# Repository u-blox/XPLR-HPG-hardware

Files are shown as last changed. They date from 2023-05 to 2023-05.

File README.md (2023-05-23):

# xplr-hpg-hw

This repository holds the design files for u-blox [XPLR-HPG-1](https://www.u-blox.com/en/product/xplr-hpg-1) and [XPLR-HPG-2](https://www.u-blox.com/en/product/xplr-hpg-2) hardware.

## [XPLR-HPG-1](https://www.u-blox.com/en/product/xplr-hpg-1)
XPLR-HPG-1 High Precision GNSS evaluation platform allows developers to evaluate the different u-blox solutions around high precision GNSS. The modular design of the base board (C213) offers users great flexibility in to explore high precision GNSS with different topologies and hardware. The design is based on the u-blox [NORA-W106](https://www.u-blox.com/en/product/nora-w10-series) that can act as a host and provides Wi-Fi and Bluetooth Low Energy v5.0 connectivity.
By using different u-blox module based MIKROE Click Boards, the user can evaluate different high precision GNSS topologies.

More info about the design can be found in the [XPLR-HPG-1 user guide](https://www.u-blox.com/en/product/xplr-hpg-1)

## [XPLR-HPG-2](https://www.u-blox.com/en/product/xplr-hpg-2)
XPLR-HPG-2 High Precision GNSS evaluation platform allows developers to evaluate the different u-blox solutions around high precision GNSS. In a simple form factor, XPLR-HPG-2 incorporates a high precision GNSS (u-blox [ZED-F9R](https://www.u-blox.com/en/product/zed-f9r-module)), an LTE Cat-1 cellular modem (u-blox [LARA-R6001D](https://www.u-blox.com/en/product/lara-r6-series)), a correction data L-BAND receiver (u-blox [NEO-D9S](https://www.u-blox.com/en/product/neo-d9s-series)) and a Wi-Fi capable host (u-blox [NINA-W106](https://www.u-blox.com/en/product/nina-w10-series-open-cpu)) to orchestrate the High precision GNSS functionality.

More info about the design can be found in the [XPLR-HPG-2 user guide](https://www.u-blox.com/en/product/xplr-hpg-2)

Software examples and libraries for both kits can be found in the [XPLR-HPG-Software](https://github.com/u-blox/XPLR-HPG-software) repo.

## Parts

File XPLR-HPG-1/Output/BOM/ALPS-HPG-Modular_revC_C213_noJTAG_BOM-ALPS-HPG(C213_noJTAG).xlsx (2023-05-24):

Line # | Designator | Quantity | Manufacturer 1 | Manufacturer Part Number 1 | Fitted | Supplier 1 | Supplier Part Number 1
 | BATT1 | 1 | Keystone Electronics | 1042 | Fitted | Mouser | 534-1042
 | BATT1_A, J3, J7 | 0 | Harwin | M20-9990246 | Not Fitted | Mouser | 855-M20-9990246
 | BATT1_B | 0 | JST | B2B-PH-SM4-TBT(LF)(SN) | Not Fitted | Future Electronics | 6881312
 | BTN1, BTN2 | 2 | TE Connectivity | FSMRA5JH | Fitted | Mouser | 506-1-1825027-4
 | BTN3 | 1 | ITT C&K | PTS526SK15SMTR2LFS | Fitted | Mouser | 611-PTS526SK15SMR2L
 | C1_1, C1_2, C1_3, C4, C6_1, C6_2, C22 | 7 | Yageo | CC0402KRX7R7BB104 | Fitted | Mouser | 603-CC402KRX7R7BB104
 | C2 | 1 | Murata | GRM155R61E105KA12D | Fitted | Mouser | 81-GRM155R61E105KA2D
 | C3, C9 | 2 | Murata | GRM21BR61E106KA73K | Fitted | Mouser | 81-GRM21BR61E106KA3K
 | C5 | 1 | Samsung | CL21A475KAQNNNG | Fitted | Mouser | 187-CL21A475KAQNNNG
 | C7, C8 | 0 | Murata | GCM1555C1H301FA16D | Not Fitted | Mouser | 81-GCM1555C1H301FA6D
 | C10, C25, C39_1, C39_2 | 4 | Yageo | CC0402KRX7R7BB104 | Fitted | Mouser | 603-CC402KRX7R7BB104
 | C11 | 1 | Yageo | CC0402KRX7R6BB683 | Fitted | Mouser | 603-CC402KRX7R6BB683
 | C12, C13 | 2 | KEMET | C1210C476M4PACTU | Fitted | Mouser | 80-C1210C476M4P
 | C14, C15 | 2 | Kyocera AVX | 08053C225KAT2A | Fitted | Mouser | 581-08053C225K
 | C16, C18 | 2 | TDK | C2012X7R1A475K125AC | Fitted | Mouser | 810-C2012X7R1A475K
 | C17, C19 | 2 | Yageo | CC0603KRX7R7BB104 | Fitted | Mouser | 603-CC603KRX7R7BB104
 | C20 | 1 | KEMET | C1210C476M4PACTU | Fitted | Mouser | 80-C1210C476M4P
 | C21, C29 | 2 | Yageo | CC0402KRX7R7BB104 | Fitted | Mouser | 603-CC402KRX7R7BB104
 | C23, C24 | 2 | Murata | GRM1885C1H102JA01D | Fitted | Mouser | 81-GRM39C102J50
 | C26 | 1 | Samsung | CL32A226KOJNNNE | Fitted | Mouser | 187-CL32A226KOJNNNE
 | C27, C28 | 0 | Murata | GRM155R71C223KA01D | Not Fitted | Mouser | 81-GRM155R71C223KA01
 | C30 | 1 | Yageo | CC0402KRX7R7BB104 | Fitted | Mouser | 603-CC402KRX7R7BB104
 | C31 | 1 | Yageo | CC0603KRX5R6BB475 | Fitted | Mouser | 603-CC603KRX5R6BB475
 | C32 | 1 | Yageo | CC0402KRX5R6BB224 | Fitted | Mouser | 603-CC402KRX5R6BB224
 | C33 | 1 | Yageo | CC0603KRX7R7BB104 | Fitted | Mouser | 603-CC603KRX7R7BB104
 | C34_1, C34_2, C34_3 | 0 | KEMET | C1210C476M4PACTU | Not Fitted | Mouser | 80-C1210C476M4P
 | C35 | 1 | Murata | GRM21BR60J226ME39L | Fitted | Mouser | 81-GRM21R60J226ME39L
 | C36, C37 | 2 | Murata | GRM21BR61E226ME44L | Fitted | Mouser | 81-GRM21BR61E226ME4L
 | C38 | 1 | Murata | GCM188R72A103KA37D | Fitted | Mouser | 81-GCM188R72A103KA7D
 | C40 | 1 | Murata | GRM155R61E105KA12D | Fitted | Mouser | 81-GRM155R61E105KA2D
 | D1_1, D1_2 | 2 | Wurth Electronics | 824011 | Fitted | Mouser | 710-824011
 | D2, D10, D11 | 3 | Wurth Electronics | 150060VS75000 | Fitted | Mouser | 710-150060VS75000
 | D3 | 1 | Wurth Electronics | 150060YS75000 | Fitted | Mouser | 710-150060YS75000
 | D4, D5 | 2 | Wurth Electronics | 150060RS75000 | Fitted | Mouser | 710-150060RS75000
 | D6, D7 | 2 | ON Semiconductor | BZX84C6V2LT1G | Fitted | Mouser | 863-BZX84C6V2LT1G
 | D8, D9 | 0 | Wurth Electronics | 150060VS75000 | Not Fitted | Mouser | 710-150060VS75000
 | D12 | 1 | Nexperia | PRTR5V0U2X,215 | Fitted | Mouser | 771-PRTR5V0U2X-T/R
 | D13 | 1 | Diodes | DT1042-04SO-7 | Fitted | Mouser | 621-DT1042-04SO-7
 | F1_1, F1_2 | 2 | Murata | BLM18EG221TN1D | Fitted | Mouser | 81-BLM18EG221TN1D
 | J1 | 1 | Global Connector Technology | MEM2080-00-128-00-A | Fitted | Mouser | 640-MEM2080-0012800A
 | J2 | 1 | JST | SM03B-SRSS-TB(LF)(SN) | Fitted | Farnell | 1679118
 | J4 | 0 | Samtec | FTSH-105-01-F-DV-K | Not Fitted | Mouser | 200-FTSH10501FDVK
 | J5 | 1 | Wurth Electronics | 61300311121 | Fitted | Mouser | 710-61300311121
 | J6_1, J6_2 | 2 | JAE Electronics | DX07S024JJ3R1300 | Fitted | Mouser | 656-DX07S024JJ3R1300
 | J18 | 0 | Molex | 51281-0594 | Not Fitted | Digi-Key | WM12846DKR-ND
 | J22 | 1 | SparkFun | PRT-14417 | Fitted | Mouser | 474-PRT-14417
 | L3 | 1 | Coilcraft | XFL4020-102MEC | Fitted | Mouser | 994-XFL4020-102MEC
 | MB_1, MB_2, MB_3 | 3 |  |  | Fitted
 | NT1 | 1 | Vishay Dale | NTHS0603N02N1002JR | Fitted | Mouser | 71-NTHS0603N02N1002J
 | PCB | 1 |  | UBXH60-0001010 | Fitted
 | Q1, Q3 | 2 | Toshiba | SSM6N56FE,LM | Fitted | Mouser | 757-SSM6N56FELM
 | Q2A | 1 | ON Semiconductor | EFC6611R-TF | Fitted | Mouser | 863-EFC6611R-TF
 | Q2B | 0 | ON Semiconductor | ECH8693R-TL-W | Not Fitted | Mouser | 863-ECH8693R-TL-W
 | Q4 | 1 | ON Semiconductor | SMBT3904DW1T1G | Fitted | Mouser | 863-SMBT3904DW1T1G
 | R1, R7, R9 | 3 | Yageo | RC0402FR-07100KL | Fitted | Mouser | 603-RC0402FR-07100KL
 | R2, R86 | 0 | Yageo | RC0402JR-074K7L | Not Fitted | Mouser | 603-RC0402JR-074K7L
 | R3, R57, R59, R89 | 4 | Yageo | RC0402JR-0710KL | Fitted | Mouser | 603-RC0402JR-0710KL
 | R4 | 1 | Yageo | RC0402FR-071K5L | Fitted | Mouser | 603-RC0402FR-071K5L
 | R5_1, R5_2, R6_1, R6_2 | 4 | Panasonic | ERJ-2RKF27R0X | Fitted | Mouser | 667-ERJ-2RKF27R0X
 | R8 | 1 | Yageo | RC0402FR-07499RL | Fitted | Mouser | 603-RC0402FR-07499RL
 | R10, R11 | 2 | Panasonic | ERJ-2GEJ221X | Fitted | Mouser | 667-ERJ-2GEJ221X
 | R12, R13, R16, R18 | 0 | Yageo | RC0402FR-07100KL | Not Fitted | Mouser | 603-RC0402FR-07100KL
 | R14 | 1 | Yageo | RC0402FR-072K2L | Fitted | Mouser | 603-RC0402FR-072K2L
 | R15, R20, R35, R36, R38, R41, R53, R55, R70, R71, R78, R80, R82, R84, R85, R91 | 0 | Bourns | CR0402-J/-000GLF | Not Fitted | Mouser | 652-CR0402-J/-000GLF
 | R17, R19, R21, R34, R37, R69, R77, R79, R81, R83, R90 | 11 | Bourns | CR0402-J/-000GLF | Fitted | Mouser | 652-CR0402-J/-000GLF
 | R22, R23 | 2 | Yageo | RC0603FR-072K2L | Fitted | Mouser | 603-RC0603FR-072K2L
 | R24, R26, R28, R30, R32, R33 | 6 | Yageo | RC0402JR-071ML | Fitted | Mouser | 603-RC0402JR-071ML
 | R25, R27, R29, R31, R60, R61, R87, R88 | 8 | Yageo | RC0402JR-074K7L | Fitted | Mouser | 603-RC0402JR-074K7L
 | R39 | 0 | Yageo | RC0402JR-0710KL | Not Fitted | Mouser | 603-RC0402JR-0710KL
 | R40, R62 | 2 | Yageo | RC0805JR-070RL | Fitted | Mouser | 603-RC0805JR-070RL
 | R42, R51 | 2 | Yageo | RC0603JR-073K3L | Fitted | Mouser | 603-RC0603JR-073K3L
 | R43 | 1 | Yageo | RC0402FR-0722KL | Fitted | Mouser | 603-RC0402FR-0722KL
 | R44 | 1 | Yageo | RC0402FR-0747KL | Fitted | Mouser | 603-RC0402FR-0747KL
 | R45 | 0 | Yageo | RC0603JR-070RL | Not Fitted | Mouser | 603-RC0603JR-070RL
 | R46, R56, R58 | 3 | Yageo | RC0603JR-070RL | Fitted | Mouser | 603-RC0603JR-070RL
 | R47, R73 | 2 | Yageo | RC0402FR-071KL | Fitted | Mouser | 603-RC0402FR-071KL
 | R48, R52 | 2 | Yageo | RC0603FR-07470RL | Fitted | Mouser | 603-RC0603FR-07470RL
 | R49, R50 | 2 | Panasonic | ERJ-3EKF9100V | Fitted | Mouser | 667-ERJ-3EKF9100V
 | R54_1, R54_2, R67_1, R67_2 | 4 | Panasonic | ERJ-2GEJ512X | Fitted | Mouser | 667-ERJ-2GEJ512X
 | R63 | 1 | Yageo | RC0402FR-0716KL | Fitted | Mouser | 603-RC0402FR-0716KL
 | R64 | 1 | Panasonic | ERJ-2RKF3003X | Fitted | Mouser | 667-ERJ-2RKF3003X
 | R65 | 1 | Yageo | RC0402FR-07100KL | Fitted | Mouser | 603-RC0402FR-07100KL
 | R66 | 1 | Panasonic | ERJ-2RKF1003X | Fitted | Mouser | 667-ERJ-2RKF1003X
 | R68_1, R68_2 | 2 | Yageo | RC0402JR-0710KL | Fitted | Mouser | 603-RC0402JR-0710KL
 | R72 | 1 | Yageo | RC0402FR-071KL | Fitted | Mouser | 603-RC0402FR-071KL
 | R74 | 1 | Panasonic | ERJ-2RKF4700X | Fitted | Mouser | 667-ERJ-2RKF4700X
 | R75 | 0 | KOA Speer | RK73Z2BTTD | Not Fitted | Mouser | 660-RK73Z2BTTD
 | R76 | 0 | Yageo | RC0805JR-070RL | Not Fitted | Mouser | 603-RC0805JR-070RL
 | R92 | 1 | Yageo | RC0402FR-0747KL | Fitted | Mouser | 603-RC0402FR-0747KL
 | RGB | 1 | Vishay Lite-On | LTST-C19HE1WT | Fitted | Mouser | 859-LTST-C19HE1WT
 | SW1 | 1 | ITT C&K | OS102011MA1QN1 | Fitted | Mouser | 611-OS102011MA1QN1
 | U1 | 1 | u-blox | NORA-W106-00B | Fitted | Mouser | 377-NORA-W106-00B
 | U2 | 0 | Macronix | MX25R6435FZNIL0 | Not Fitted | Future Electronics | 5069038
 | U3A | 1 | Silicon Labs | CP2102N-A02-GQFN24 | Fitted | Mouser | 634-CP2102NA02GQFN24
 | U4 | 1 | ABLIC | S-82N1AAA-I6T1U7 | Fitted | Mouser | 628-S-82N1AAA-I6T1U7
 | U5 | 1 | Broadcom Avago | HCPL-073L-000E | Fitted | Mouser | 630-HCPL-073L-000E
 | U6 | 1 | Texas Instruments | SN74LVC2G07DBVR | Fitted | Mouser | 595-SN74LVC2G07DBVR
 | U7 | 1 | Texas Instruments | TPS61230ARNSR | Fitted | Mouser | 595-TPS61230ARNSR
 | U8 | 1 | ON Semiconductor | NCP690MN33T2G | Fitted | Mouser | 863-NCP690MN33T2G
 | U9B | 1 | Texas Instruments | SN74LVC1G06DBVR | Fitted | Mouser | 595-SN74LVC1G06DBVR
 | U10 | 1 | Maxim | MAX8934DETI+ | Fitted | Mouser | 700-MAX8934DETI+

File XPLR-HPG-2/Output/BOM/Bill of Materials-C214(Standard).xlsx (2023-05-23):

Designator | Quantity | Manufacturer 1 | Manufacturer Part Number 1 | Fitted | Supplier 1 | Supplier Part Number 1
BT1 | 1 | Seiko | ML414H-IV01E | Fitted | Mouser | 628-ML414H-IV01E
C1, C3, C5, C7, C12, C13, C35, C49 | 8 | KEMET | C0603C105M4RACTU | Fitted | Mouser | 80-C0603C105M4R
C2, C4, C6, C9, C11, C17, C19, C25, C26, C31, C32, C36 | 12 | KEMET | C0603C104J3RACTU | Fitted | Mouser | 80-C0603C104J3R
C8 | 1 | KEMET | C0603C102K5RACTU | Fitted | Mouser | 80-C0603C102K5R
C10, C27, C28 | 3 | Murata | GRM188R6YA475KE15D | Fitted | Mouser | 81-GRM188R6YA475KE5D
C14, C15, C37, C38, C39, C40 | 6 | KEMET | C0603C470J5GACTU | Fitted | Mouser | 80-C0603C470J5G
C16 | 1 | KEMET | T520D337M006ATE045 | Fitted | Mouser | 80-T520D337M006
C18 | 1 | Murata | GRM188R60J106ME47D | Fitted | Mouser | 81-GRM188R60J106ME47
C20 | 1 | KEMET | C0603C680J5GACTU | Fitted | Mouser | 80-C0603C680J5G
C21 | 1 | Kyocera AVX | TAJA106K016RNJ | Fitted | Mouser | 581-TAJA106K016R
C22 | 1 | Kyocera AVX | 06035A150JAT2A | Fitted | Mouser | 581-06035A150J
C23, C29, C30 | 3 | Murata | GCM188R71E224KA55D | Fitted | Mouser | 81-GCM188R71E224K55D
C24 | 1 | KEMET | C0603C829K5GACTU | Fitted | Mouser | 80-C0603C829K5G
C33, C34 | 2 | Murata | GRM1555C1H330JA01D | Fitted | Arrow Electronics | GRM1555C1H330JA01D
C41 | 0 | KEMET | C0603C105M4RACTU | Not Fitted | Mouser | 80-C0603C105M4R
C42 | 1 | KEMET | C0603C104J3RACTU | Fitted | Mouser | 80-C0603C104J3R
C43 | 1 | Taiyo Yuden | TMK316BJ106MLHT | Fitted | Mouser | 963-TMK316BJ106MLHT
C44, C46 | 2 | KEMET | C0603C105M4RACTU | Fitted | Mouser | 80-C0603C105M4R
C45, C48 | 2 | Taiyo Yuden | LMK316AB7226KL-TR | Fitted | Mouser | 963-LMK316AB7226KLTR
C47 | 1 | KEMET | C0603C104J3RACTU | Fitted | Mouser | 80-C0603C104J3R
C50 | 0 | Murata | GRM32EE70J107ME15L | Not Fitted | Mouser | 81-GRM32EE70J107ME5L
C51, C52 | 0 |  |  | Not Fitted
D1, D4, D7, D19 | 4 | Osram Opto | LB Q39G-L2OO-35-1 | Fitted | Mouser | 720-LBQ39GL2N2351
D2 | 1 | Vishay Lite-On | LTST-C190YKT | Fitted | Mouser | 859-LTST-C190YKT
D3, D9, D17, D20 | 4 | Vishay Lite-On | LTST-C190EKT | Fitted | Mouser | 859-LTST-C190EKT
D5, D12, D13 | 3 | Littelfuse | PESD0402-140 | Fitted | Mouser | 650-PESD0402-140
D6 | 1 | Nexperia | PMEG4005EJ,115 | Fitted | Arrow Electronics | PMEG4005EJ,115
D8, D18 | 2 | Vishay Lite-On | LTST-C190KGKT | Fitted | Mouser | 859-LTST-C190KGKT
D10 | 1 | Wurth Electronics | 824011 | Fitted | Mouser | 710-824011
D11, D16 | 2 | Diodes | DT1042-04SO-7 | Fitted | Mouser | 621-DT1042-04SO-7
D14 | 1 | Nexperia | PRTR5V0U2X,215 | Fitted | Mouser | 771-PRTR5V0U2X-T/R
E1, E2, E3 | 3 | Amphenol Connex | 132322 | Fitted | Mouser | 523-132322
F1 | 1 | Littelfuse | 1210L200SLYR | Fitted | Mouser | 576-1210L200SLYR
F2, F3 | 2 | Murata | BLM18EG221TN1D | Fitted | Mouser | 81-BLM18EG221TN1D
F4 | 1 | Littelfuse | 1206L110THYR | Fitted | Mouser | 576-1206L110THYR
J1 | 1 | Global Connector Technology | USB4105-GF-A | Fitted | Mouser | 640-USB4105-GF-A
J2, J5 | 0 | Amphenol ICC / FCI | 77311-418-12LF | Not Fitted | Mouser | 649-77311-418-12LF
J3 | 1 | Global Connector Technology | MEM2075-00-140-01-A | Fitted | Mouser | 640-MEM20750014001A
J4 | 0 | Global Connector Technology | BG301-03-A-0540-L-B | Not Fitted | Future Electronics | 7018791
J6 | 1 | SparkFun | PRT-14417 | Fitted | Mouser | 474-PRT-14417
J7 | 1 | Adafruit Industries | 1769 | Fitted | Mouser | 485-1769
J8 | 0 | Harwin | M20-9990246 | Not Fitted | Mouser | 855-M20-9990246
J9 | 1 | Hirose | KP13B-SF-PEJ(800) | Fitted | Mouser | 798-KP13B-SF-PEJ800
J10 | 0 | Amphenol ICC / FCI | 68422-410HLF | Not Fitted | Mouser | 649-68422-410HLF
J11 | 0 | Samtec | FTSH-105-01-F-DV-K | Not Fitted | Mouser | 200-FTSH10501FDVK
L1, L2 | 0 |  |  | Not Fitted
L3 | 1 | Murata | DFE322520FD-1R5M=P2 | Fitted | Mouser | 81-DFE322520FD1R5MP2
L4 | 1 | Murata | LQG15HN47NJ02D | Fitted | Mouser | 81-LQG15HN47NJ02D
L5, L6 | 2 | Murata | LQG15HN12NG02D | Fitted | Mouser | 81-LQG15HN12NG02D
PCB | 1 |  | UBXH60-0000969 | Fitted
Q1 | 1 | ON Semiconductor | MBT3904DW1T1G | Fitted | Mouser | 863-MBT3904DW1T1G
Q2, Q3, Q5, Q6 | 4 | ON Semiconductor / Fairchild | 2N7002KW | Fitted | Mouser | 512-2N7002KW
R1, R9, R11, R14, R32, R34, R38, R42, R43, R46, R49 | 11 | Yageo | RC0603FR-07100KL | Fitted | Mouser | 603-RC0603FR-07100KL
R2, R6, R10, R39, R40, R44, R47, R48, R50 | 9 | Yageo | RC0603FR-071KL | Fitted | Mouser | 603-RC0603FR-071KL
R3 | 1 | Yageo | RC0603FR-072K7L | Fitted | Mouser | 603-RC0603FR-072K7L
R4 | 1 | Yageo | RC0603FR-0747KL | Fitted | Mouser | 603-RC0603FR-0747KL
R5, R7 | 2 | Yageo | RC0603FR-075K1L | Fitted | Mouser | 603-RC0603FR-075K1L
R8 | 1 | Yageo | RC0603FR-074K7L | Fitted | Mouser | 603-RC0603FR-074K7L
R12, R30 | 2 | Yageo | RC0603FR-0722KL | Fitted | Mouser | 603-RC0603FR-0722KL
R13 | 1 | Panasonic | ERJ-3EKF4752V | Fitted | Mouser | 667-ERJ-3EKF4752V
R15, R18, R19 | 3 | Yageo | RC0603FR-072K2L | Fitted | Mouser | 603-RC0603FR-072K2L
R16, R17 | 2 | Yageo | RC0603FR-0710KL | Fitted | Mouser | 603-RC0603FR-0710KL
R20, R21, R22, R23 | 4 | Panasonic | ERJ-3EKF27R0V | Fitted | Mouser | 667-ERJ-3EKF27R0V
R24 | 1 | Yageo | RC0603FR-0720KL | Fitted | Mouser | 603-RC0603FR-0720KL
R25, R45 | 2 | Yageo | RC0603FR-07100RL | Fitted | Mouser | 603-RC0603FR-07100RL
R26, R27, R28, R56, R58 | 5 | Yageo | RC0603FR-072KL | Fitted | Mouser | 603-RC0603FR-072KL
R29 | 1 | Yageo | RC0603FR-071KL | Fitted | Mouser | 603-RC0603FR-071KL
R31 | 1 | Yageo | RC0603FR-0733KL | Fitted | Mouser | 603-RC0603FR-0733KL
R33, R51, R64, R67 | 0 | Yageo | RC0603FR-100RL | Not Fitted | Mouser | 603-RC0603FR-100RL
R35, R59, R60, R61 | 4 | Yageo | RC0603FR-0710KL | Fitted | Mouser | 603-RC0603FR-0710KL
R36 | 1 | Yageo | RC0603FR-07200KL | Fitted | Mouser | 603-RC0603FR-07200KL
R37 | 1 | Panasonic | ERJ-P06D16R9V | Fitted | Mouser | 667-ERJ-P06D16R9V
R41 | 1 | Yageo | RC0603FR-07220RL | Fitted | Mouser | 603-RC0603FR-07220RL
R53, R55 | 0 | Yageo | RC0603FR-100RL | Not Fitted | Mouser | 603-RC0603FR-100RL
R54 | 1 | Yageo | RC0603FR-100RL | Fitted | Mouser | 603-RC0603FR-100RL
R57 | 1 | Yageo | RC0603FR-0721KL | Fitted | Mouser | 603-RC0603FR-0721KL
R62 | 1 | Yageo | RC0603FR-0757K6L | Fitted | Mouser | 603-RC0603FR-0757K6L
R63 | 1 | Yageo | RC0603FR-074K7L | Fitted | Mouser | 603-RC0603FR-074K7L
R65 | 1 | Yageo | RC0603FR-0710KL | Fitted | Mouser | 603-RC0603FR-0710KL
R66 | 1 | Yageo | RC0603FR-100RL | Fitted | Mouser | 603-RC0603FR-100RL
R68 | 0 | Yageo | RC0603FR-0710KL | Not Fitted | Mouser | 603-RC0603FR-0710KL
S1, S2, S3 | 3 | ITT C&K | PTS526SK15SMTR2LFS | Fitted | Mouser | 611-PTS526SK15SMR2L
U1 | 1 | u-blox | NINA-W106-10B | Fitted | Mouser | 377-NINA-W106-10B
U2 | 1 | Silicon Labs | CP2102N-A02-GQFN24 | Fitted | Mouser | 634-CP2102NA02GQFN24
U3 | 1 | u-blox | NEO-D9S-00B | Fitted | Mouser | 377-NEO-D9S-00B
U4 | 1 | u-blox | ZED-F9R-02B | Fitted | Digi-Key | 672-ZED-F9R-02BCT-ND
U5 | 1 | Anaren | PD0922J5050S2HF | Fitted | Mouser | 620-PD0922J5050S2HF
U6 | 1 | u-blox | LARA-R6001D-00B | Fitted | Mouser | 377-LARA-R6001D-00B
U7 | 1 | ON Semiconductor | NCP690MNADJT2G | Fitted | Mouser | 863-NCP690MNADJT2G
U8 | 1 | ON Semiconductor | NCP690MN33T2G | Fitted | Mouser | 863-NCP690MN33T2G
U9 | 1 | Texas Instruments | PCA9306DCUR | Fitted | Mouser | 595-PCA9306DCUR
U10, U13 | 2 | Nexperia | 74AVC4T774PWJ | Fitted | Mouser | 771-74AVC4T774PWJ
U11 | 1 | Texas Instruments | SN74LVC1G04DCKR | Fitted | Mouser | 595-SN74LVC1G04DCKR
U12 | 1 | Monolithic Power Systems | MP2617HGL-Z | Fitted | Mouser | 946-MP2617HGL-Z
U14 | 1 | Terminus Tech | FE1.1S-BSOP28BCN | Fitted | LCSC ELECTRONICS | C9359
Y1 | 1 | Wurth Electronics | 830036401 | Fitted | Mouser | 710-830036401

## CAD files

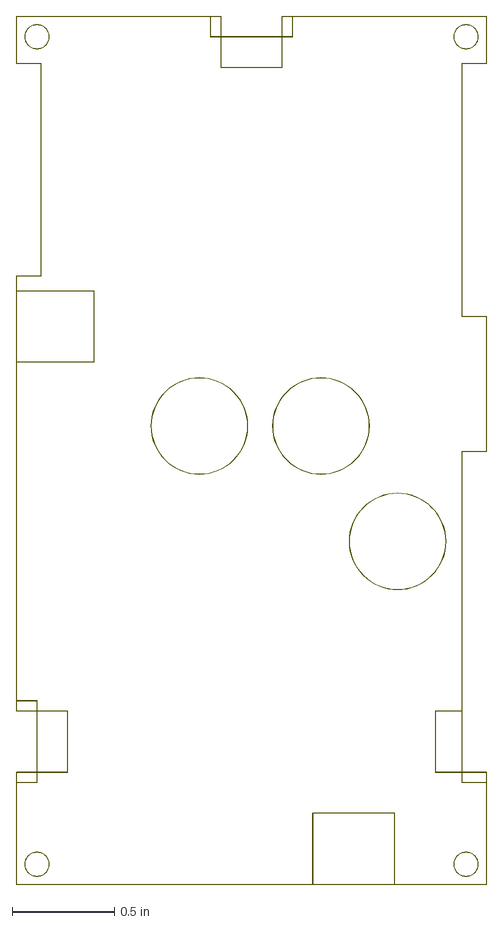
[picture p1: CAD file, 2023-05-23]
XPLR-HPG-2/Output/Plexiglass/Plexiglass_Top_Bottom.DXF
2.30 x 4.25 in

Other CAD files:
XPLR-HPG-1/Plexi Design/C213,C215_revC_Plexiglass_wLetters.dxf

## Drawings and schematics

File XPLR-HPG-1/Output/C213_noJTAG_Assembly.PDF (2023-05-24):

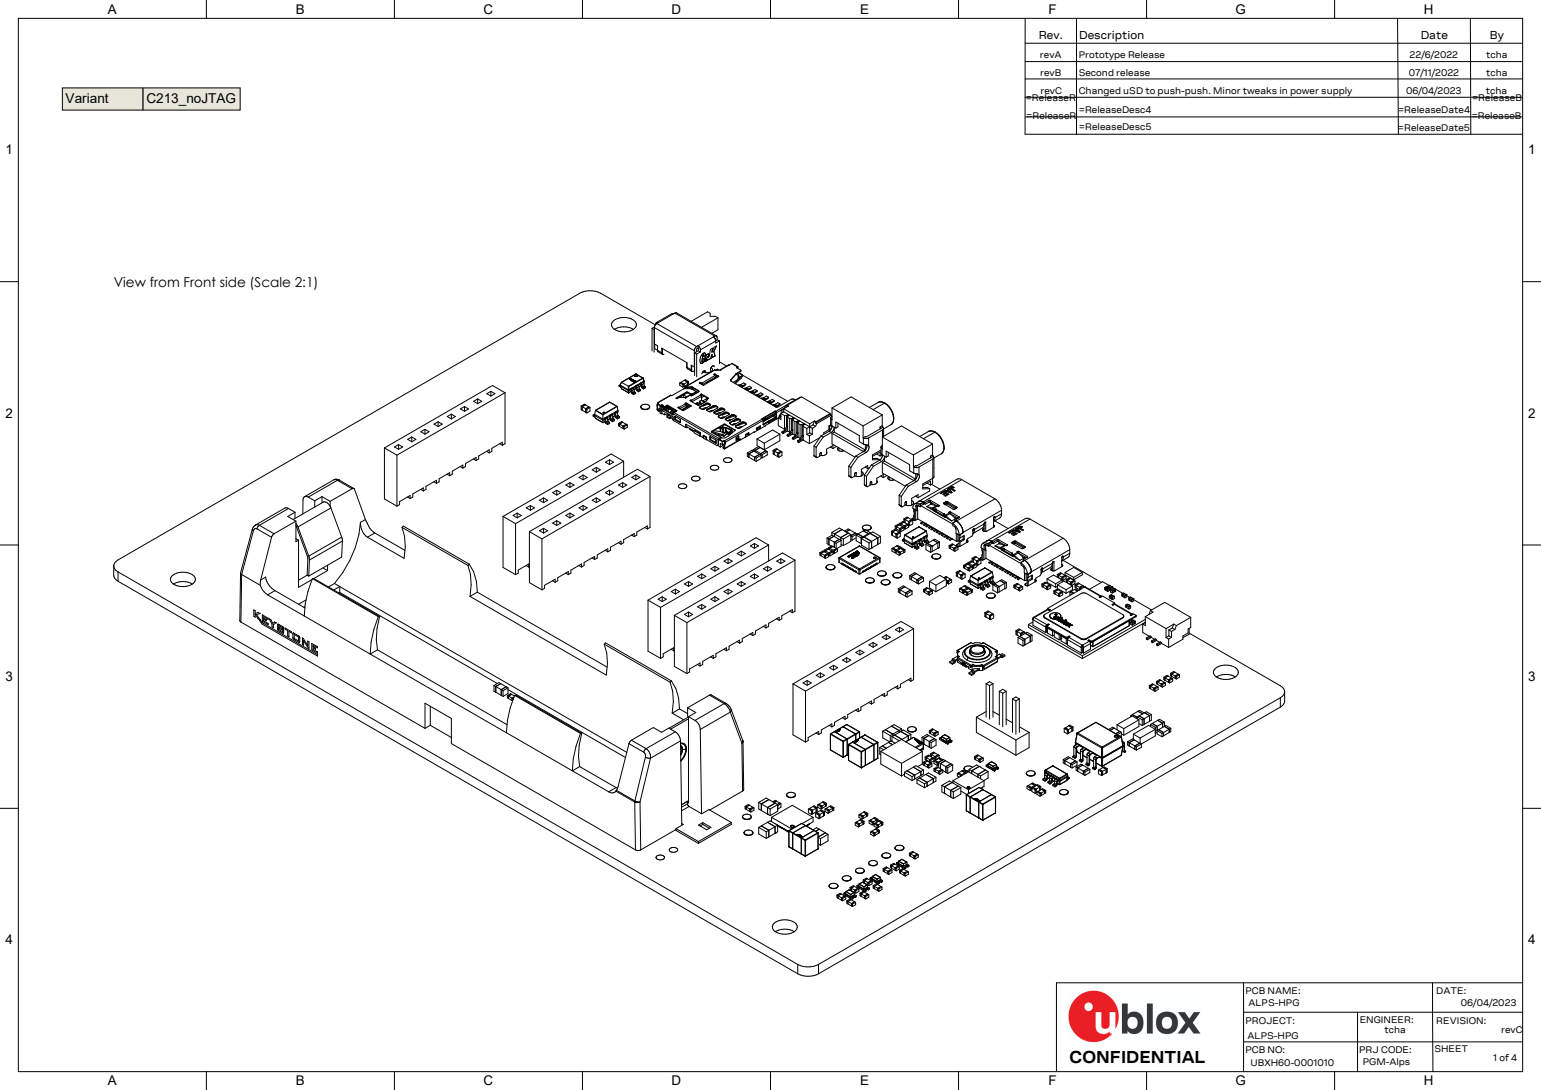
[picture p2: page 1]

Prototype Release
Second release
Changed uSD to push-push. Minor tweaks in power supply
=ReleaseDesc4
=ReleaseDesc5

View from Front side (Scale 2:1)

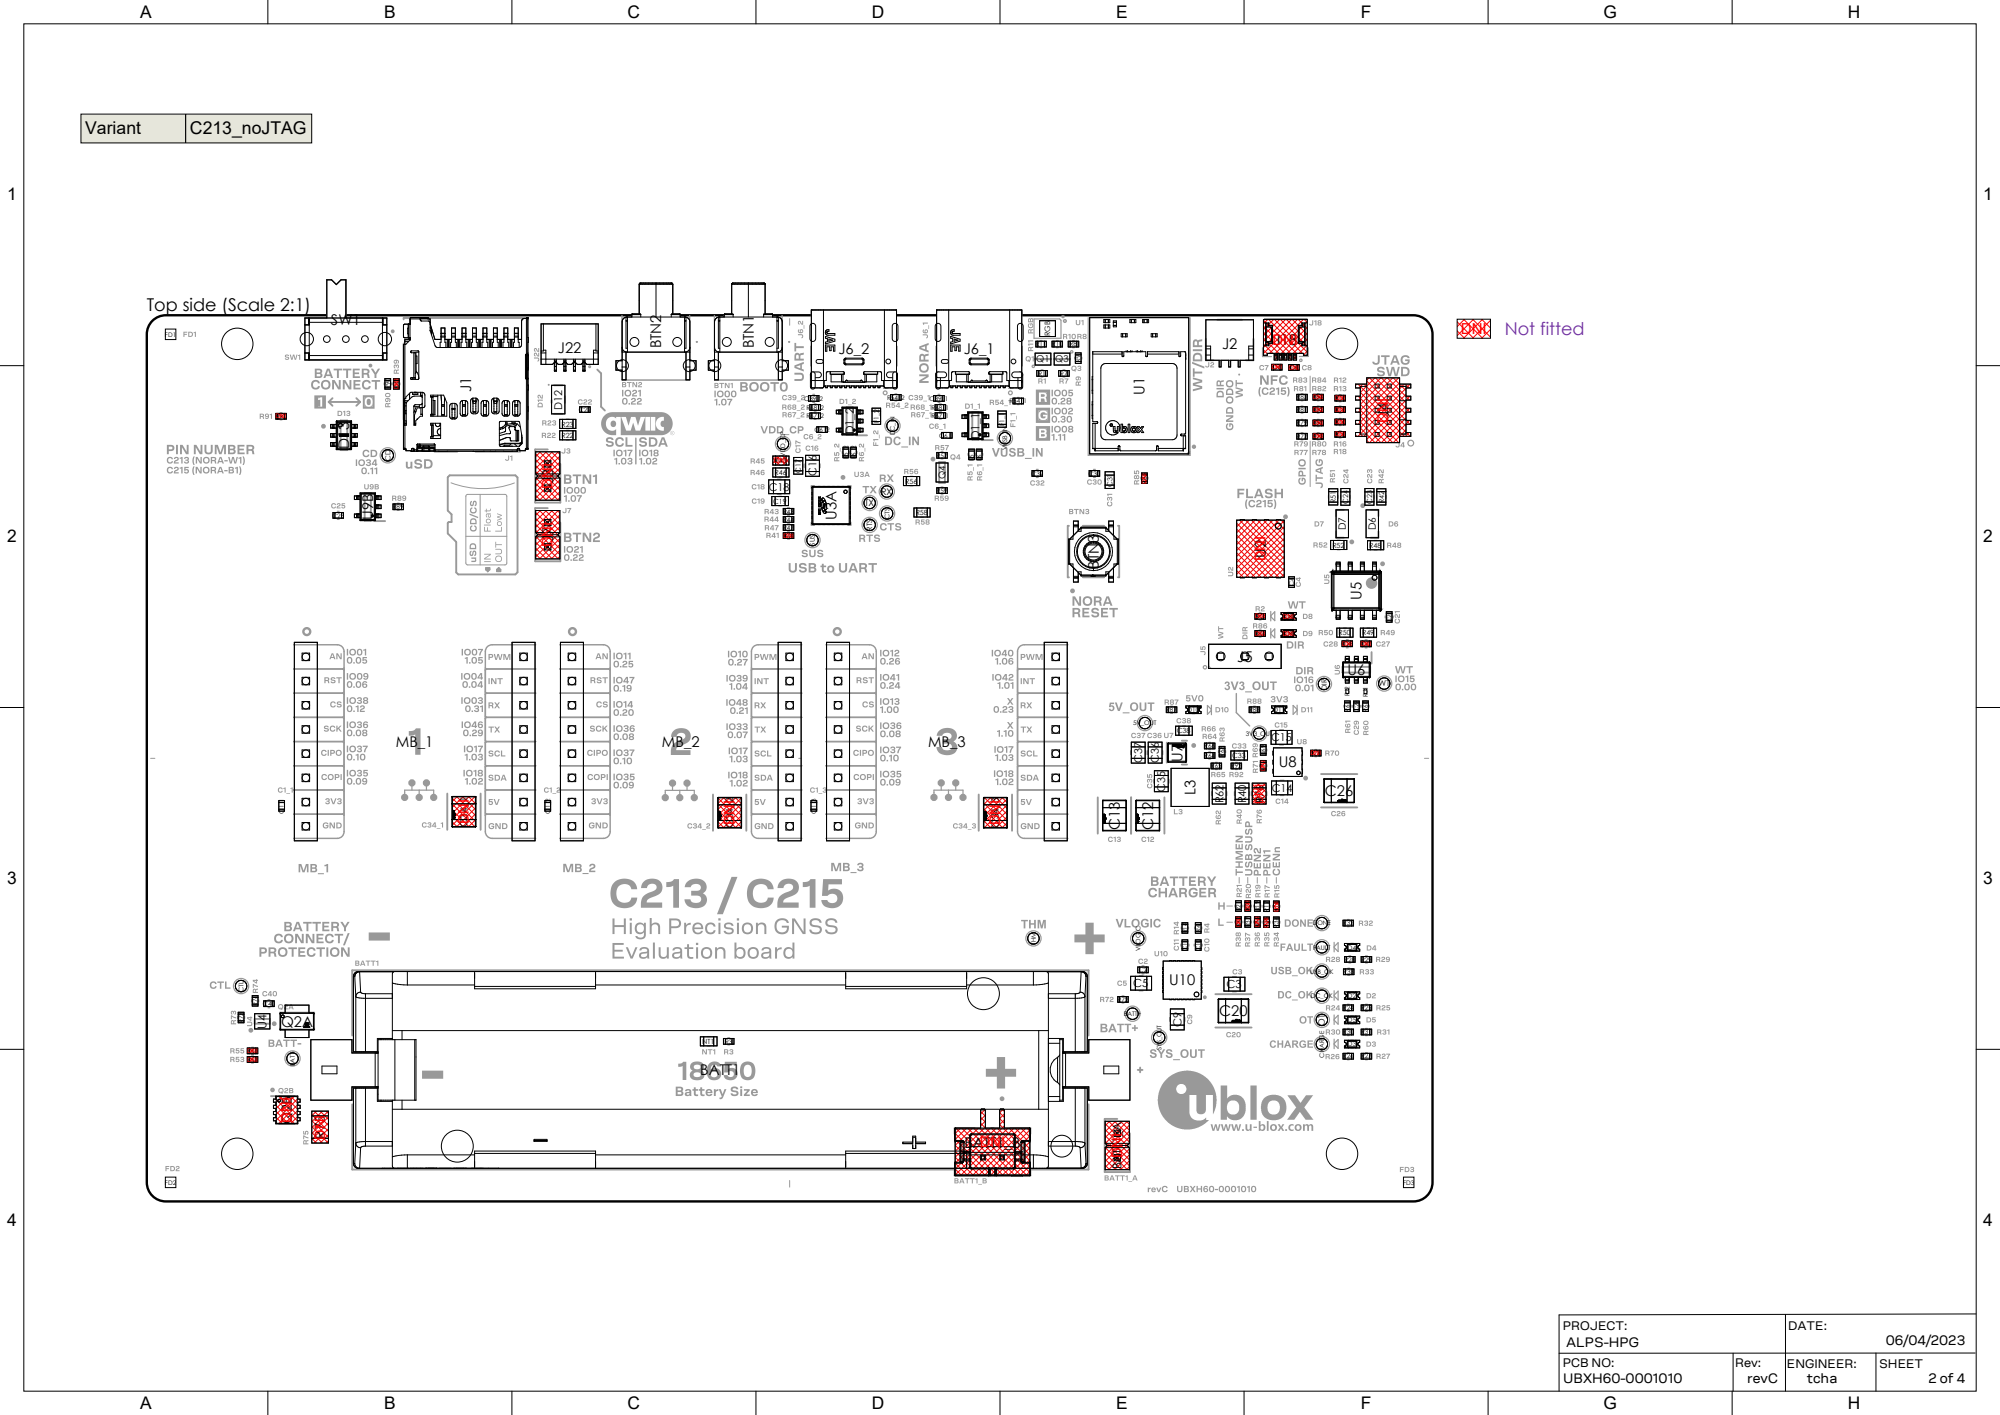
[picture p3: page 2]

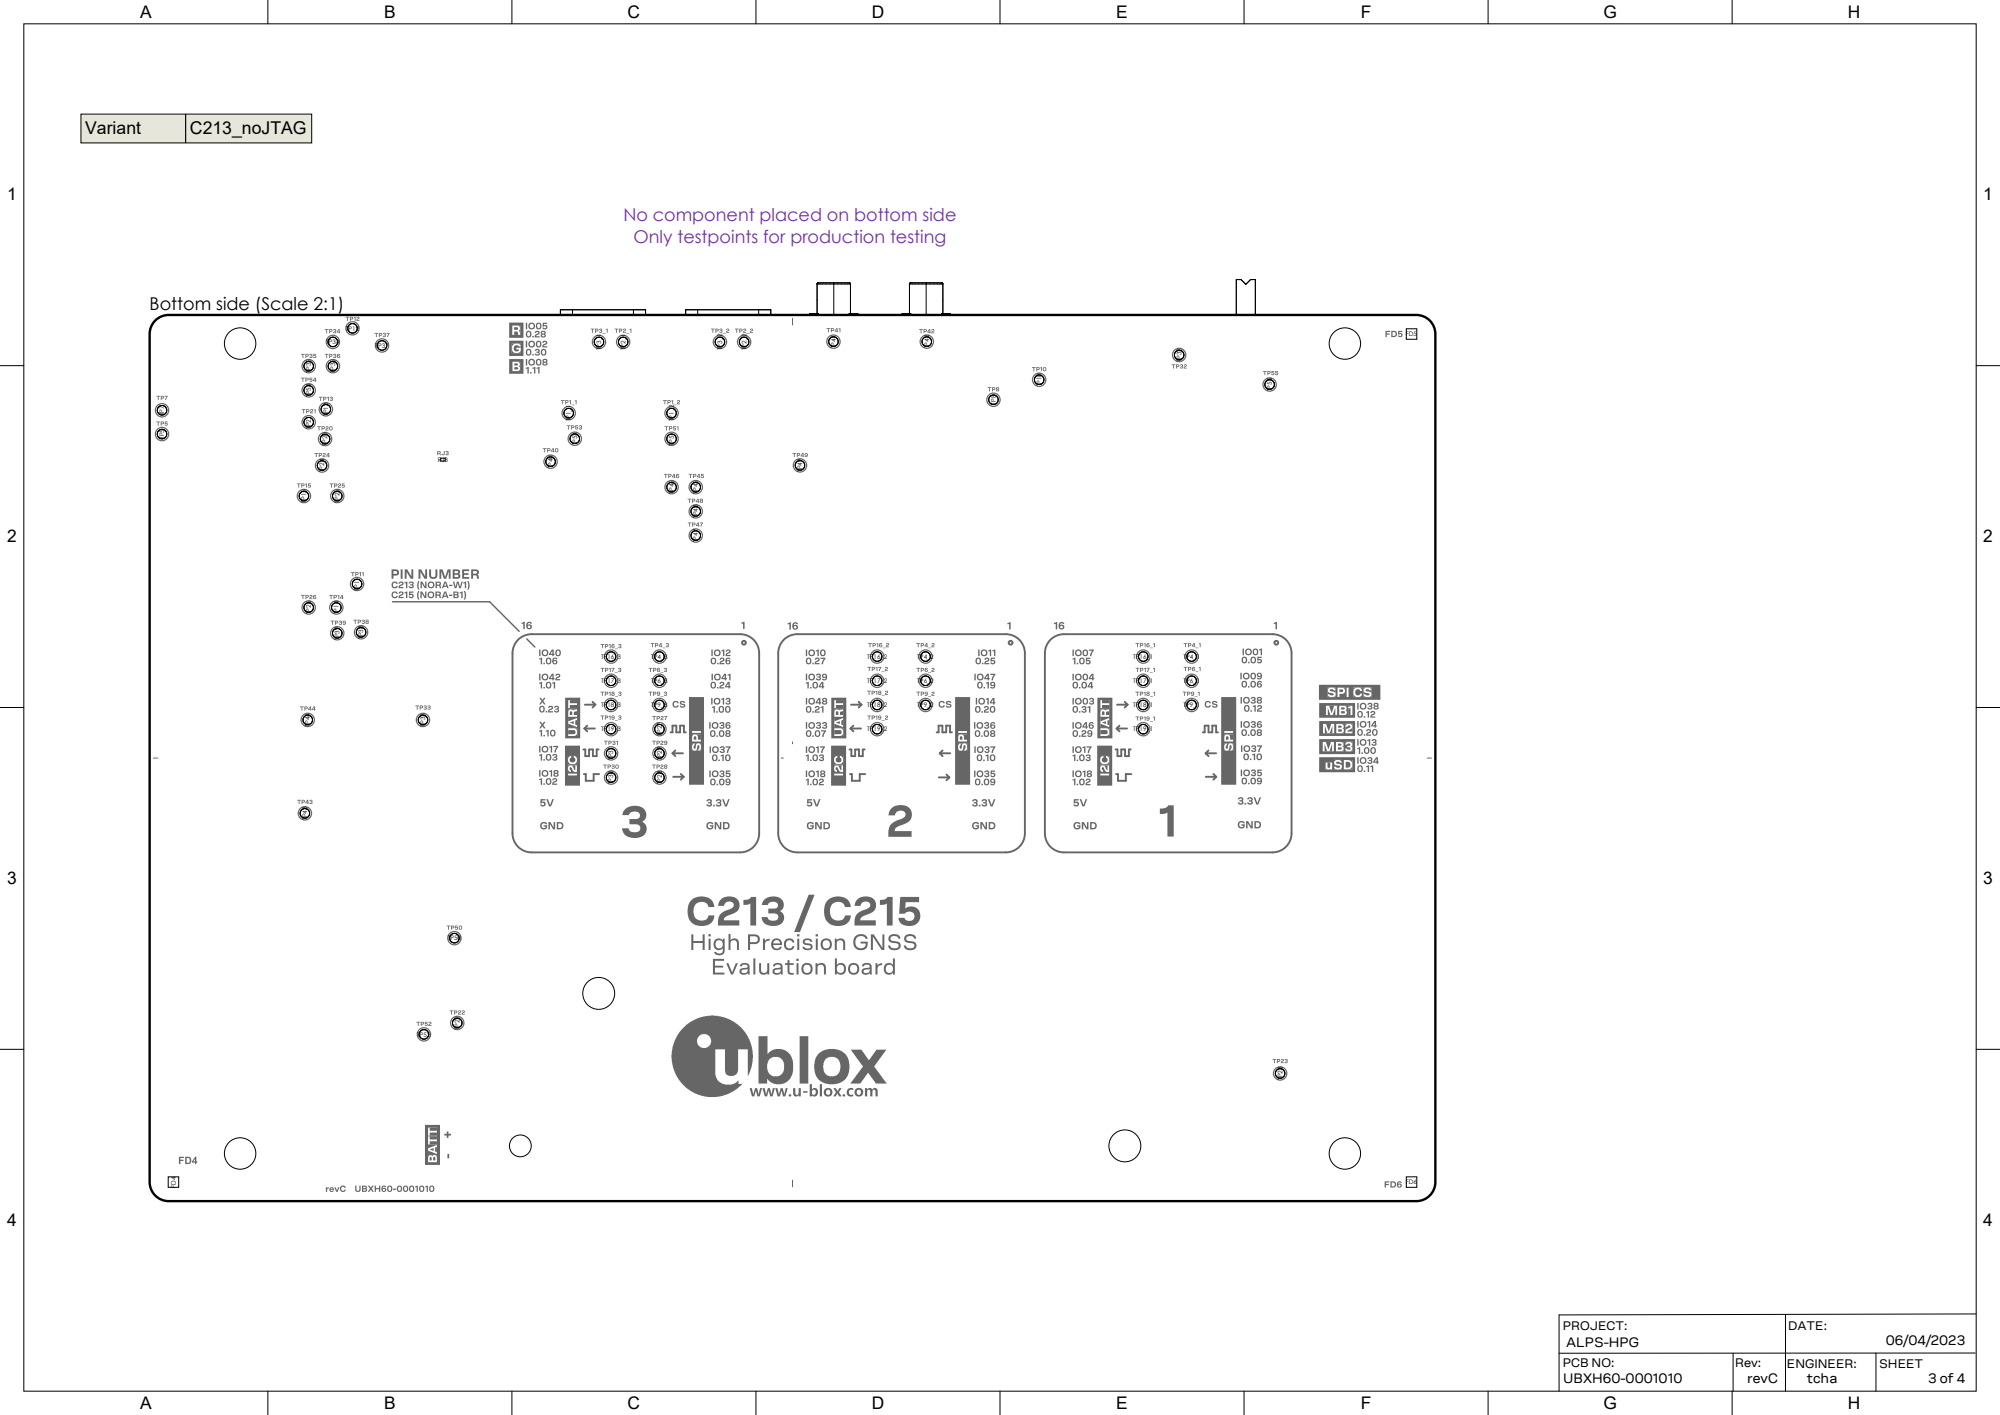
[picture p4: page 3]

No component placed on bottom side
Only testpoints for production testing

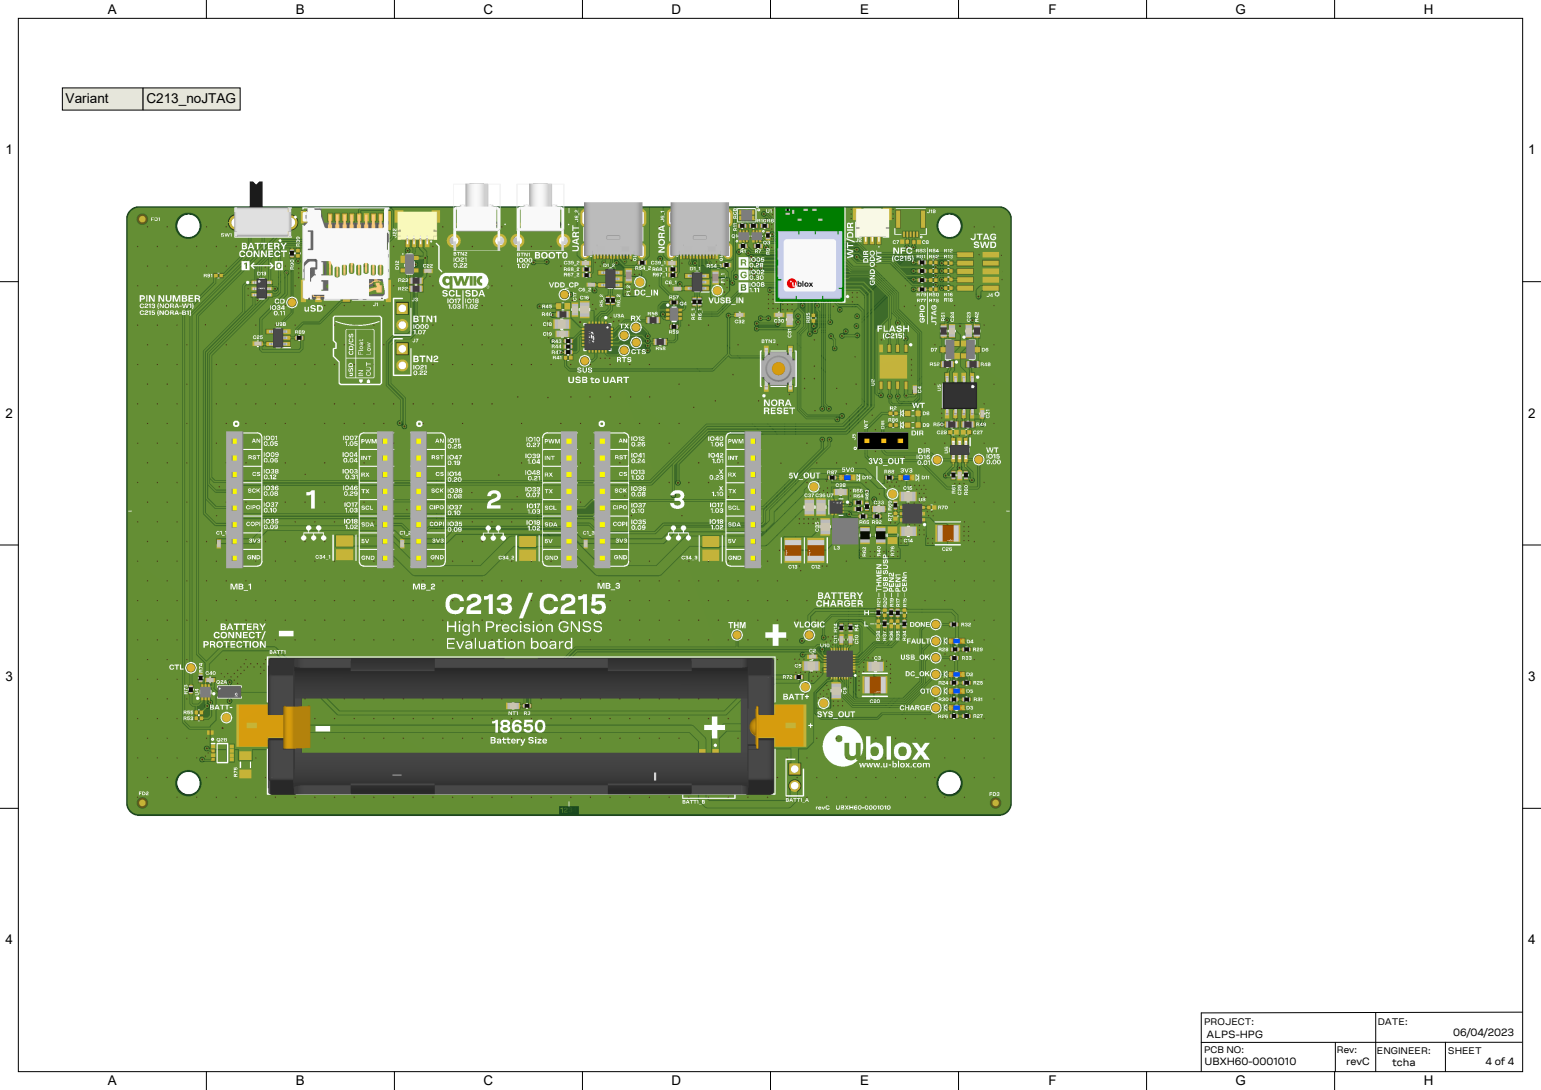
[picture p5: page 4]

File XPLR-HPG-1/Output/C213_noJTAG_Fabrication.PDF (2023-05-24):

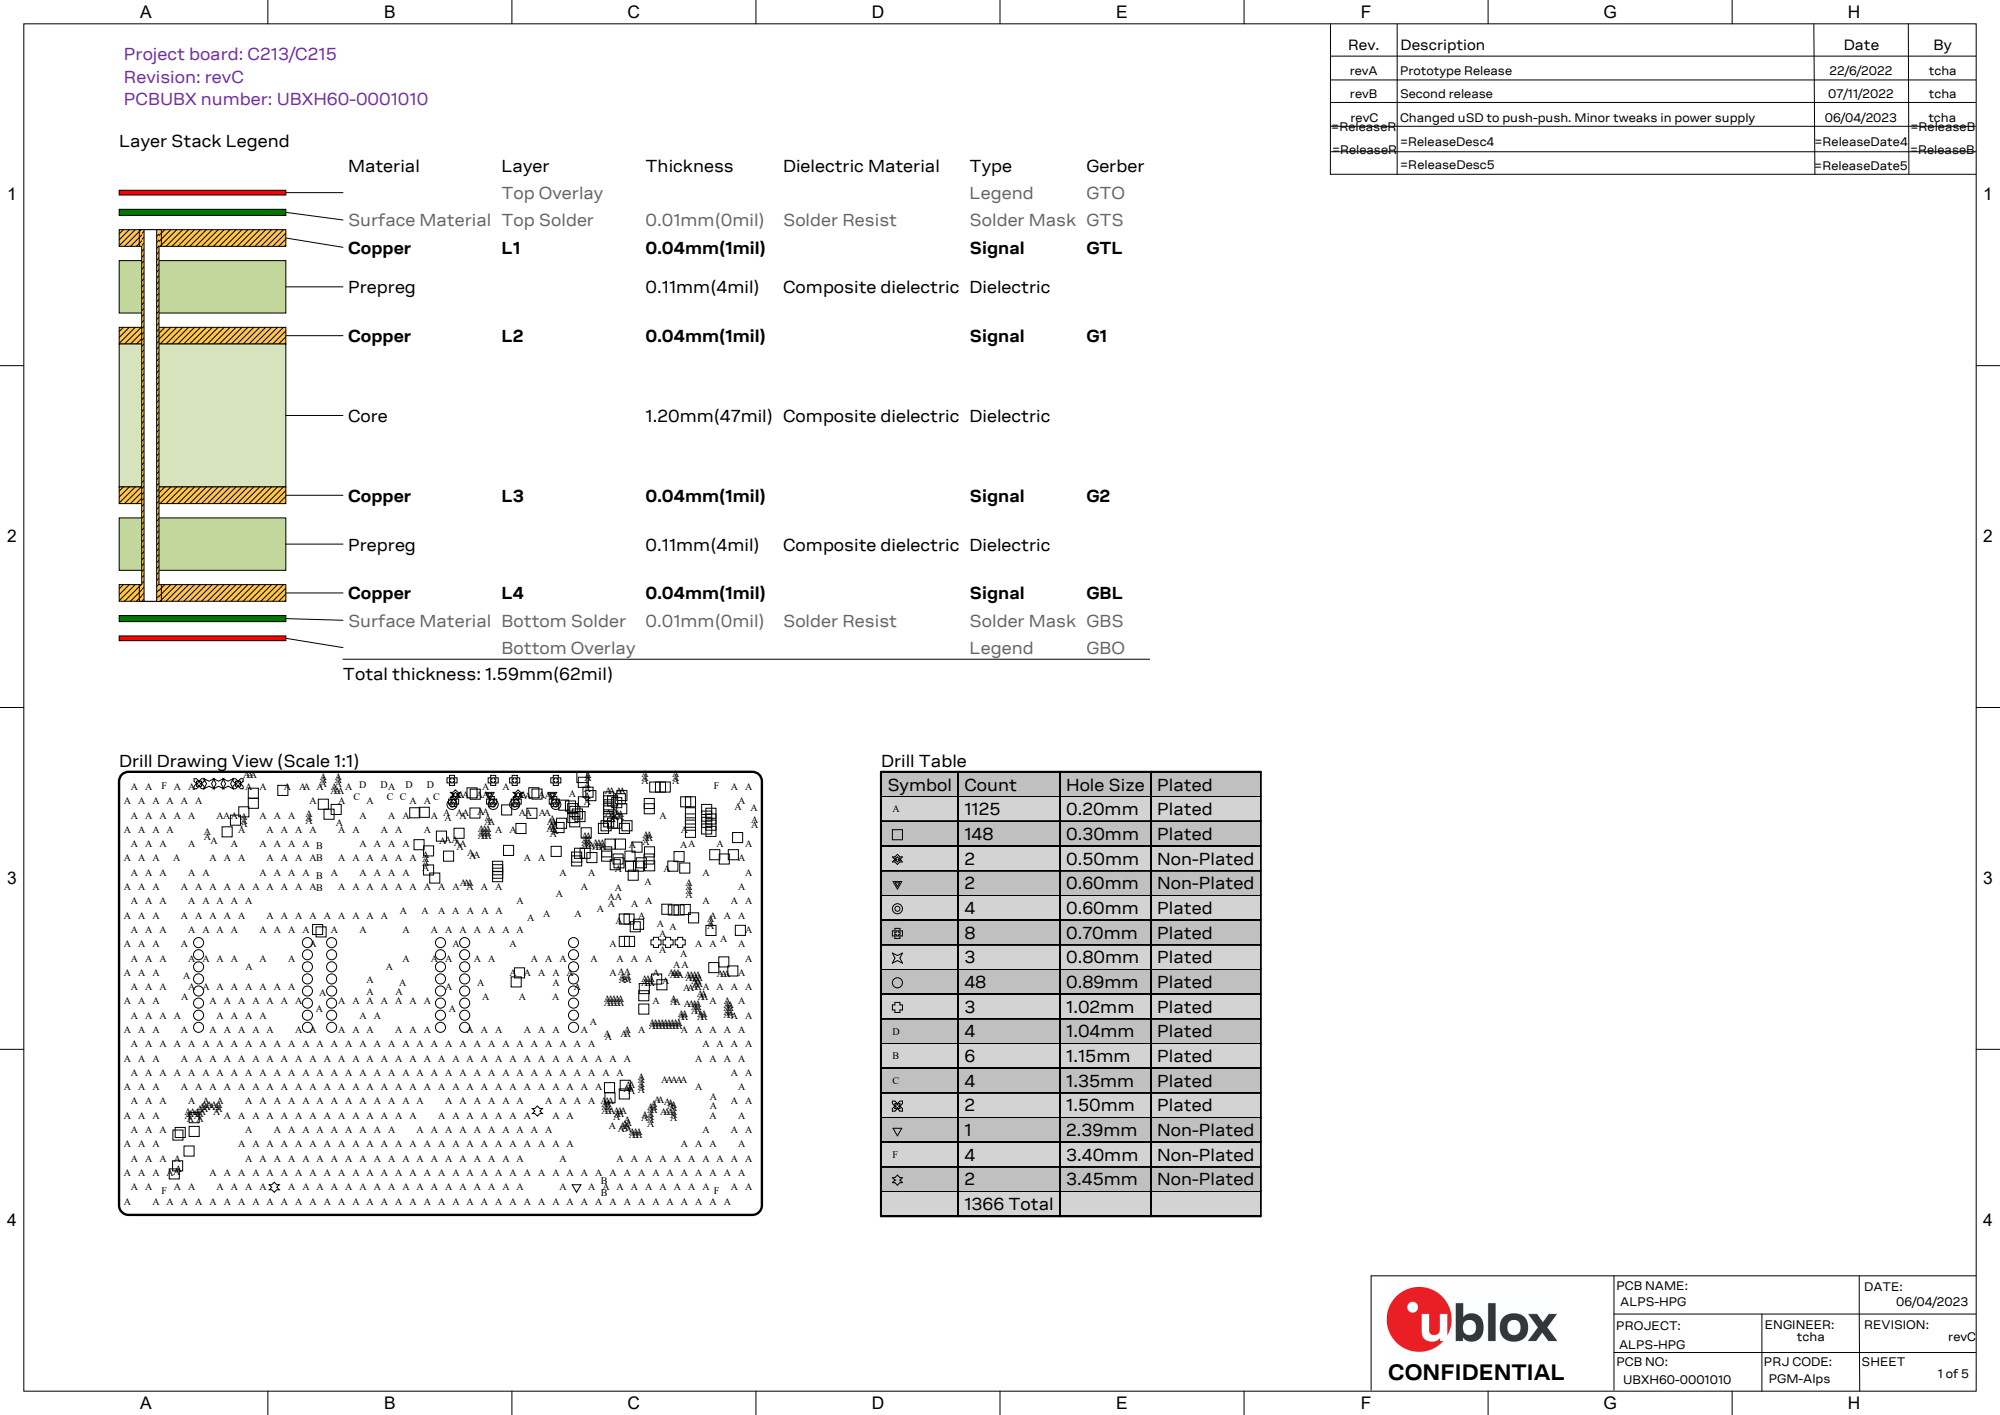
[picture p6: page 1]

Prototype Release
Second release
Changed uSD to push-push. Minor tweaks in power supply
=ReleaseDesc4
=ReleaseDesc5

Drill Drawing View (Scale 1:1)

AAAA | A AA

2 | 0.50mm | Non-Plated
2 | 0.60mm | Non-Plated
4 | 0.60mm | Plated
8 | 0.70mm | Plated

3 | 0.80mm | Plated
48 | 0.89mm | Plated
3 | 1.02mm | Plated

D | 4 | 1.04mm | Plated

B | 6 | 1.15mm | Plated

C | 4 | 1.35mm | Plated

2 | 1.50mm | Plated
1 | 2.39mm | Non-Plated

F | 4 | 3.40mm | Non-Plated

2 | 3.45mm | Non-Plated
1366 Total

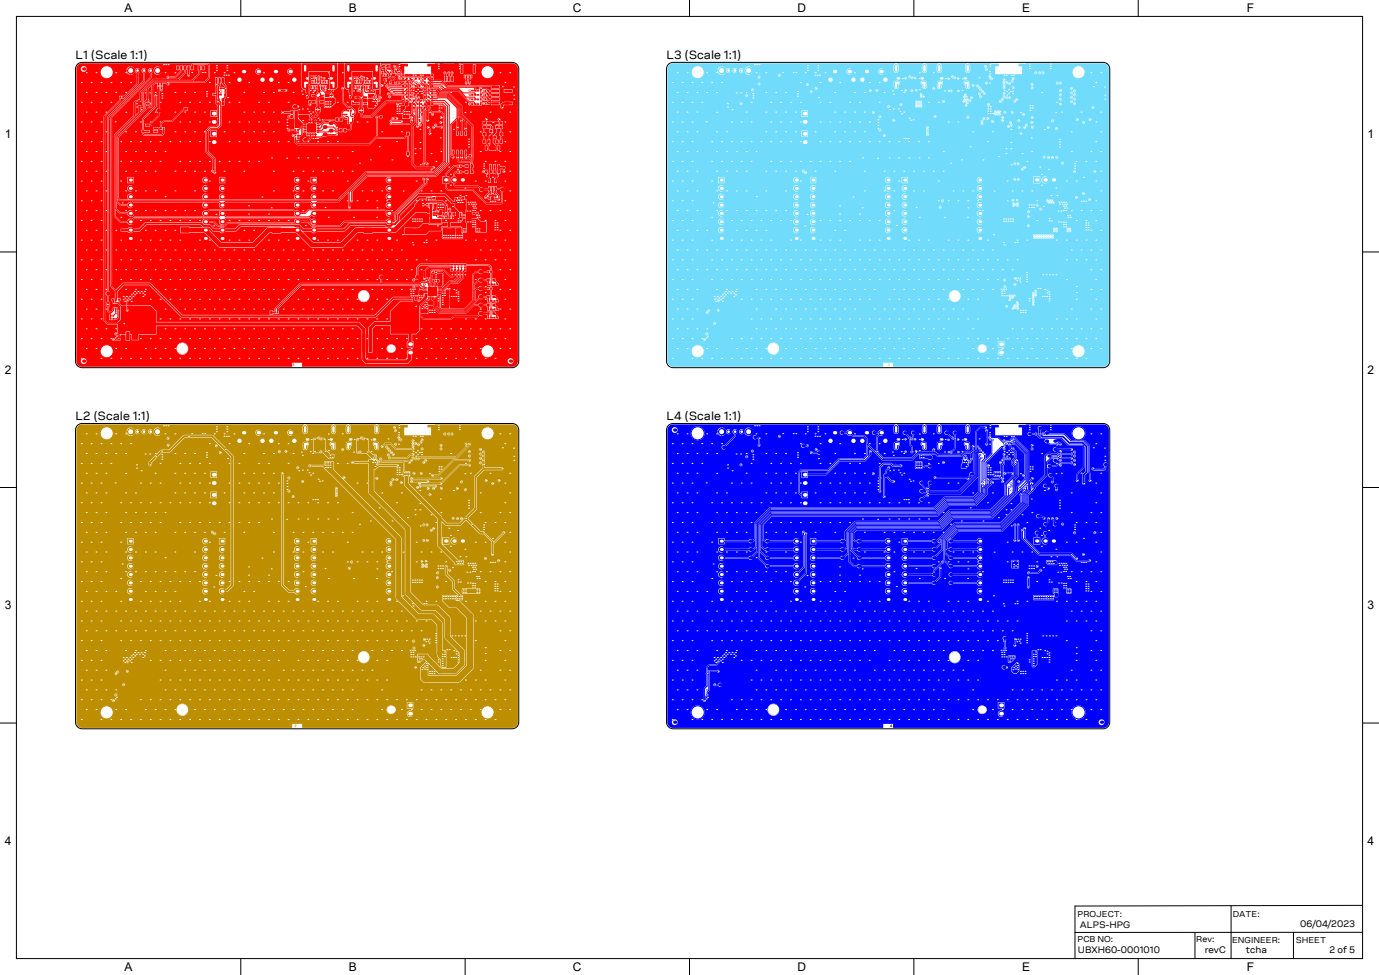
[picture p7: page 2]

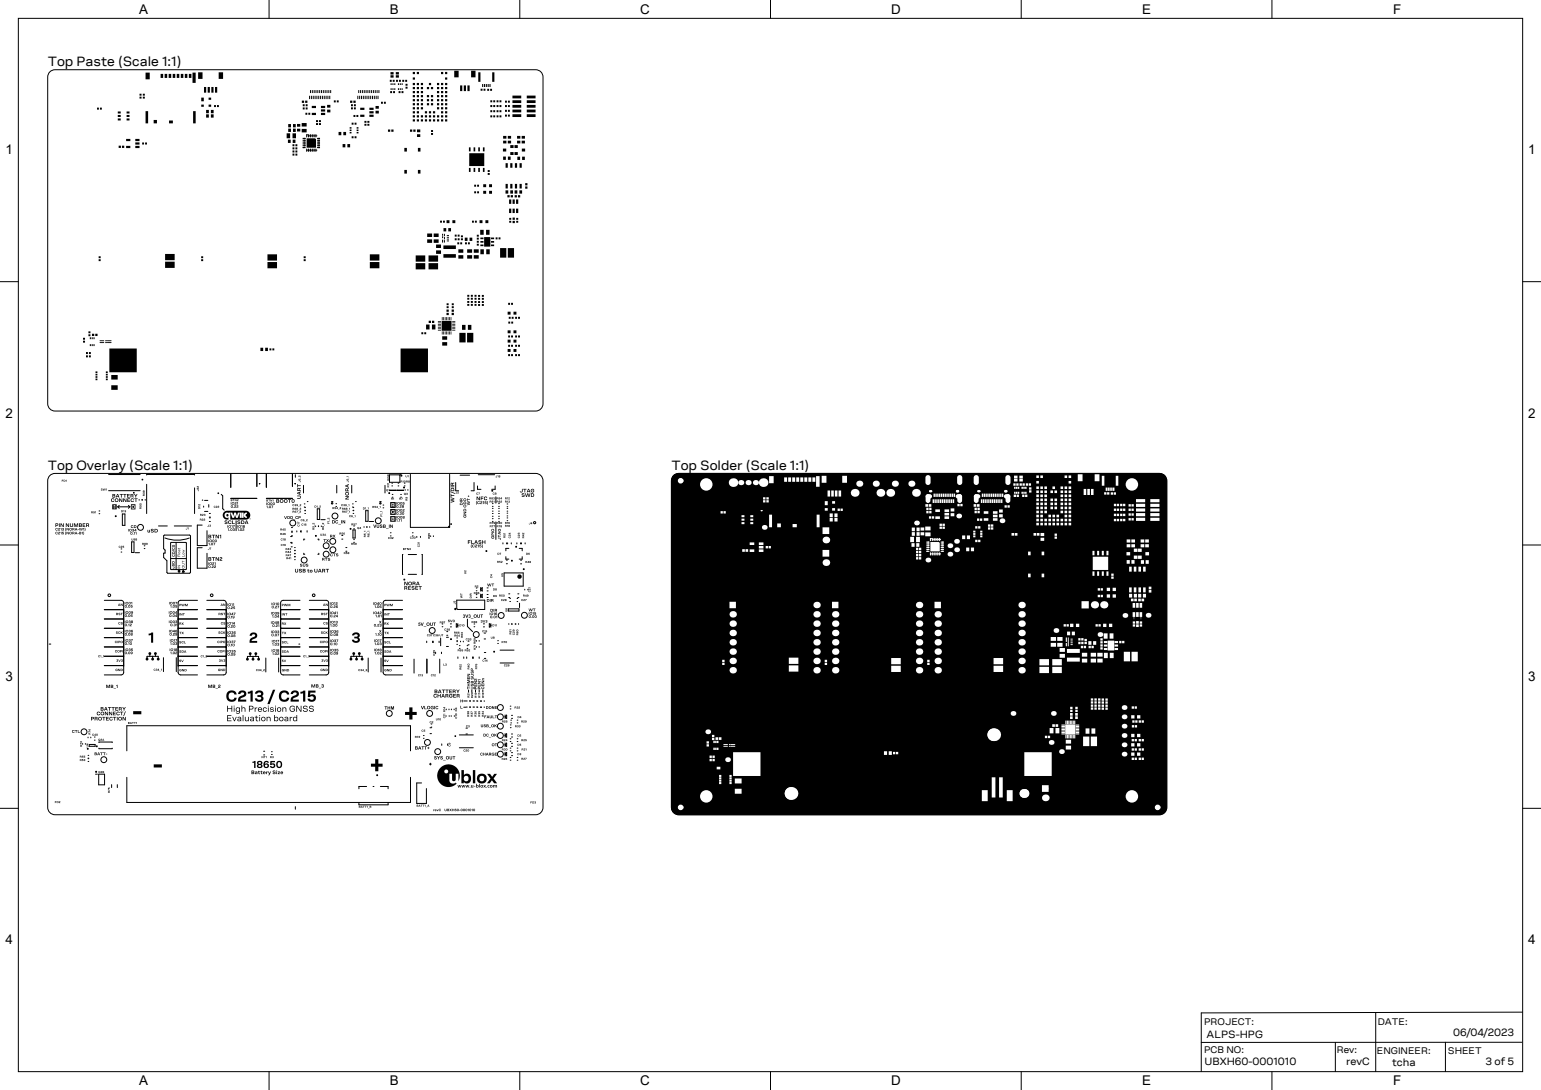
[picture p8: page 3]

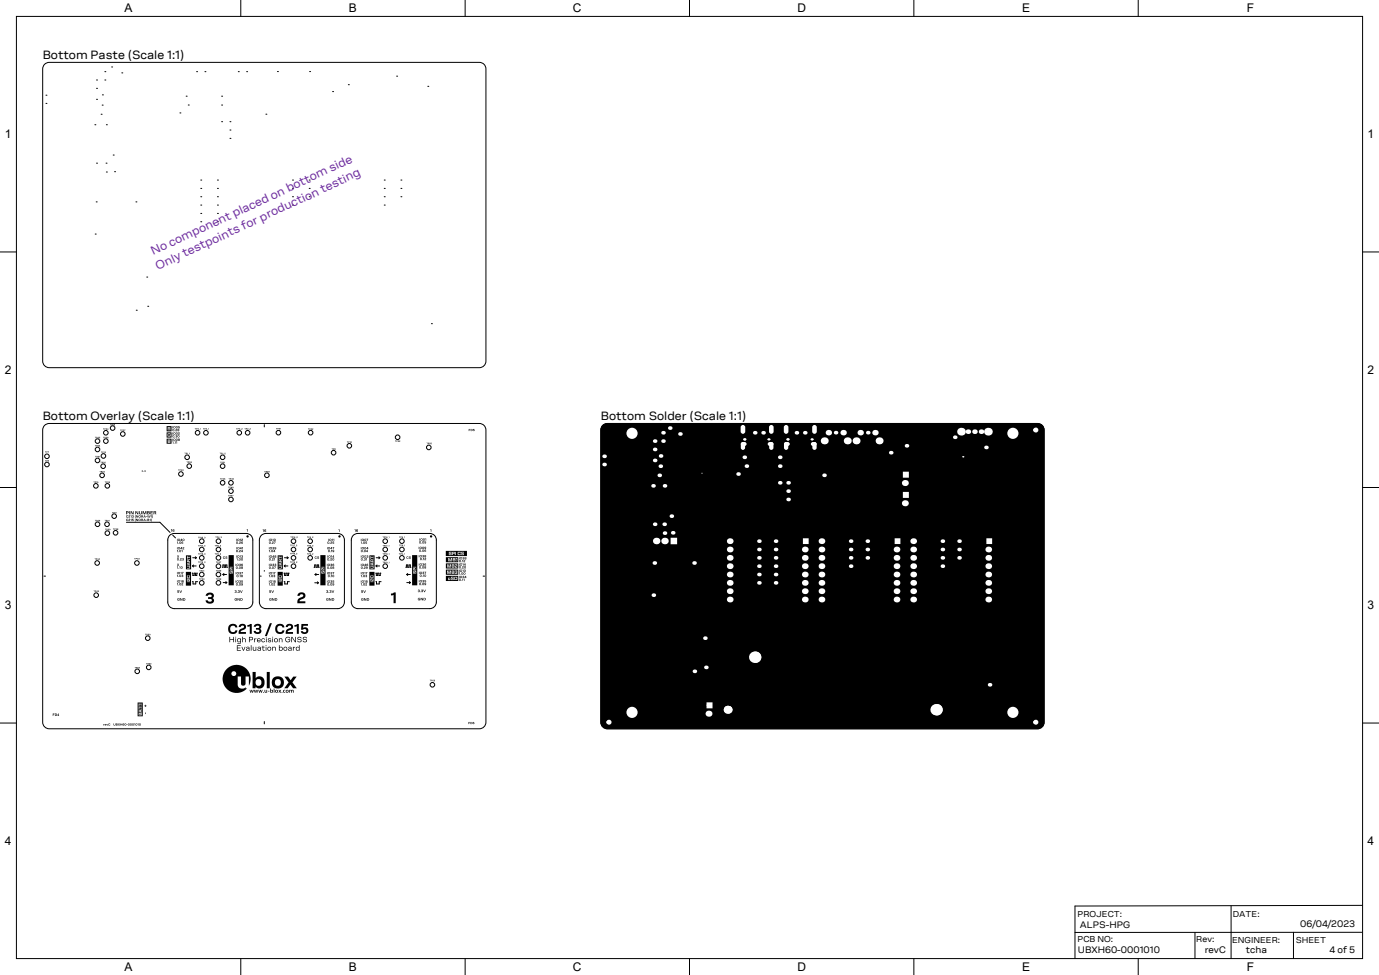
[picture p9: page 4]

No component placed on bottom side

Only testpoints for production testing

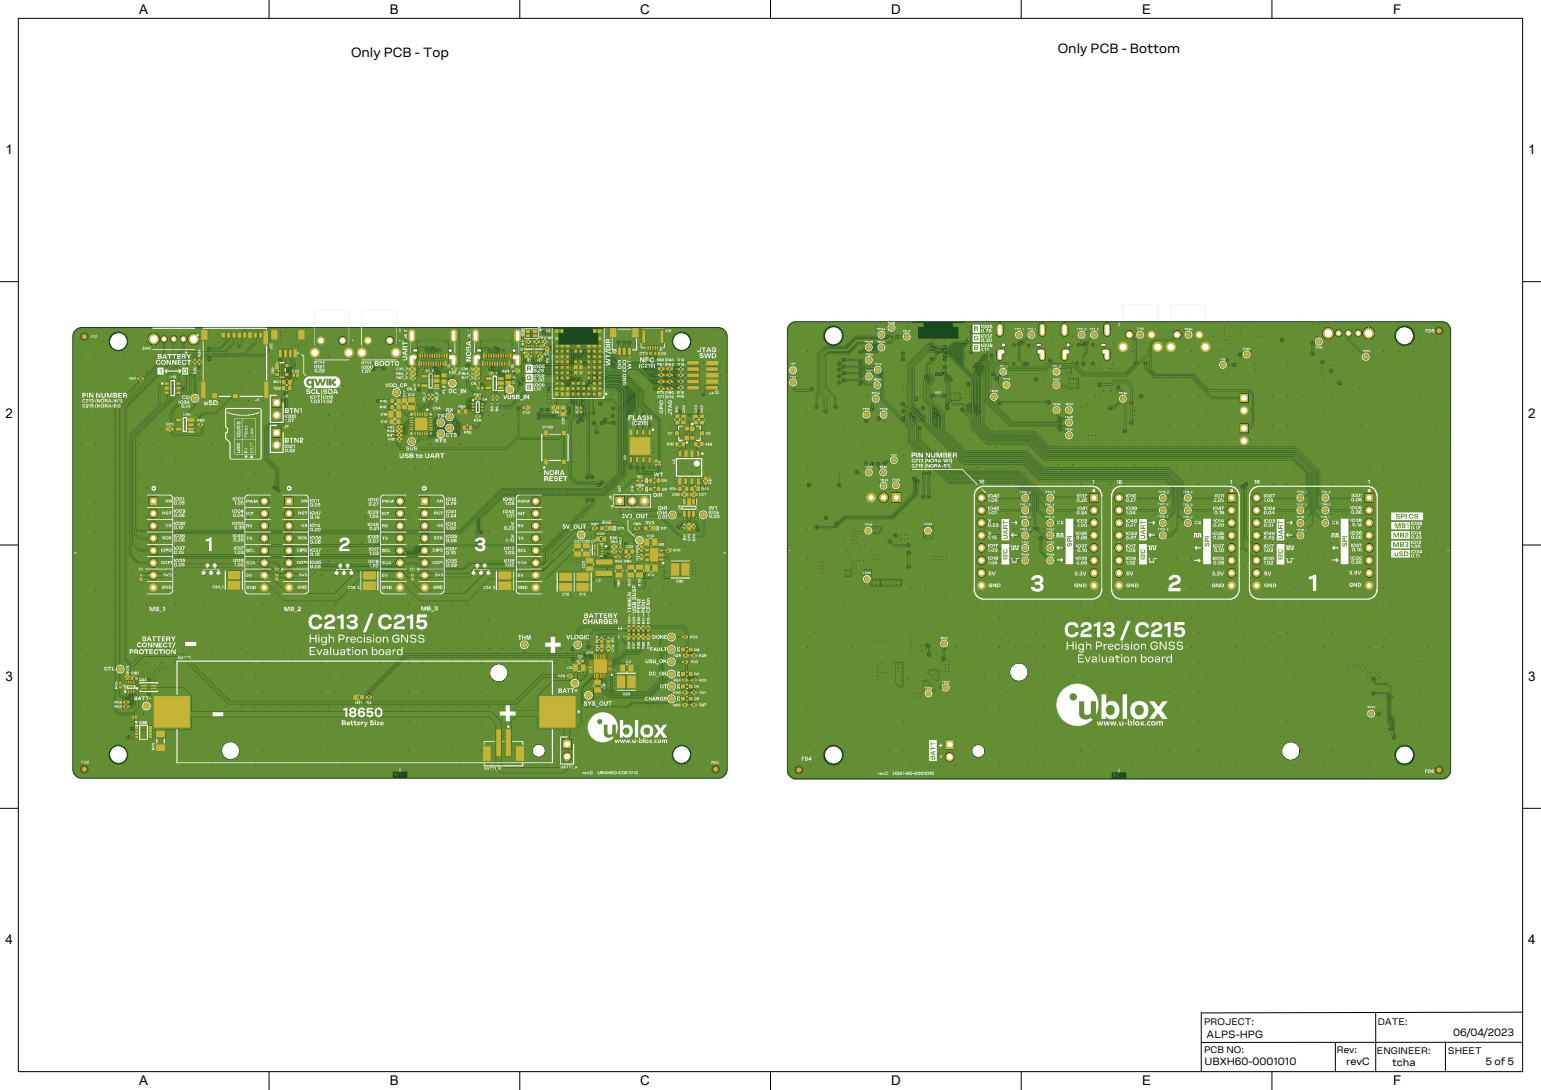
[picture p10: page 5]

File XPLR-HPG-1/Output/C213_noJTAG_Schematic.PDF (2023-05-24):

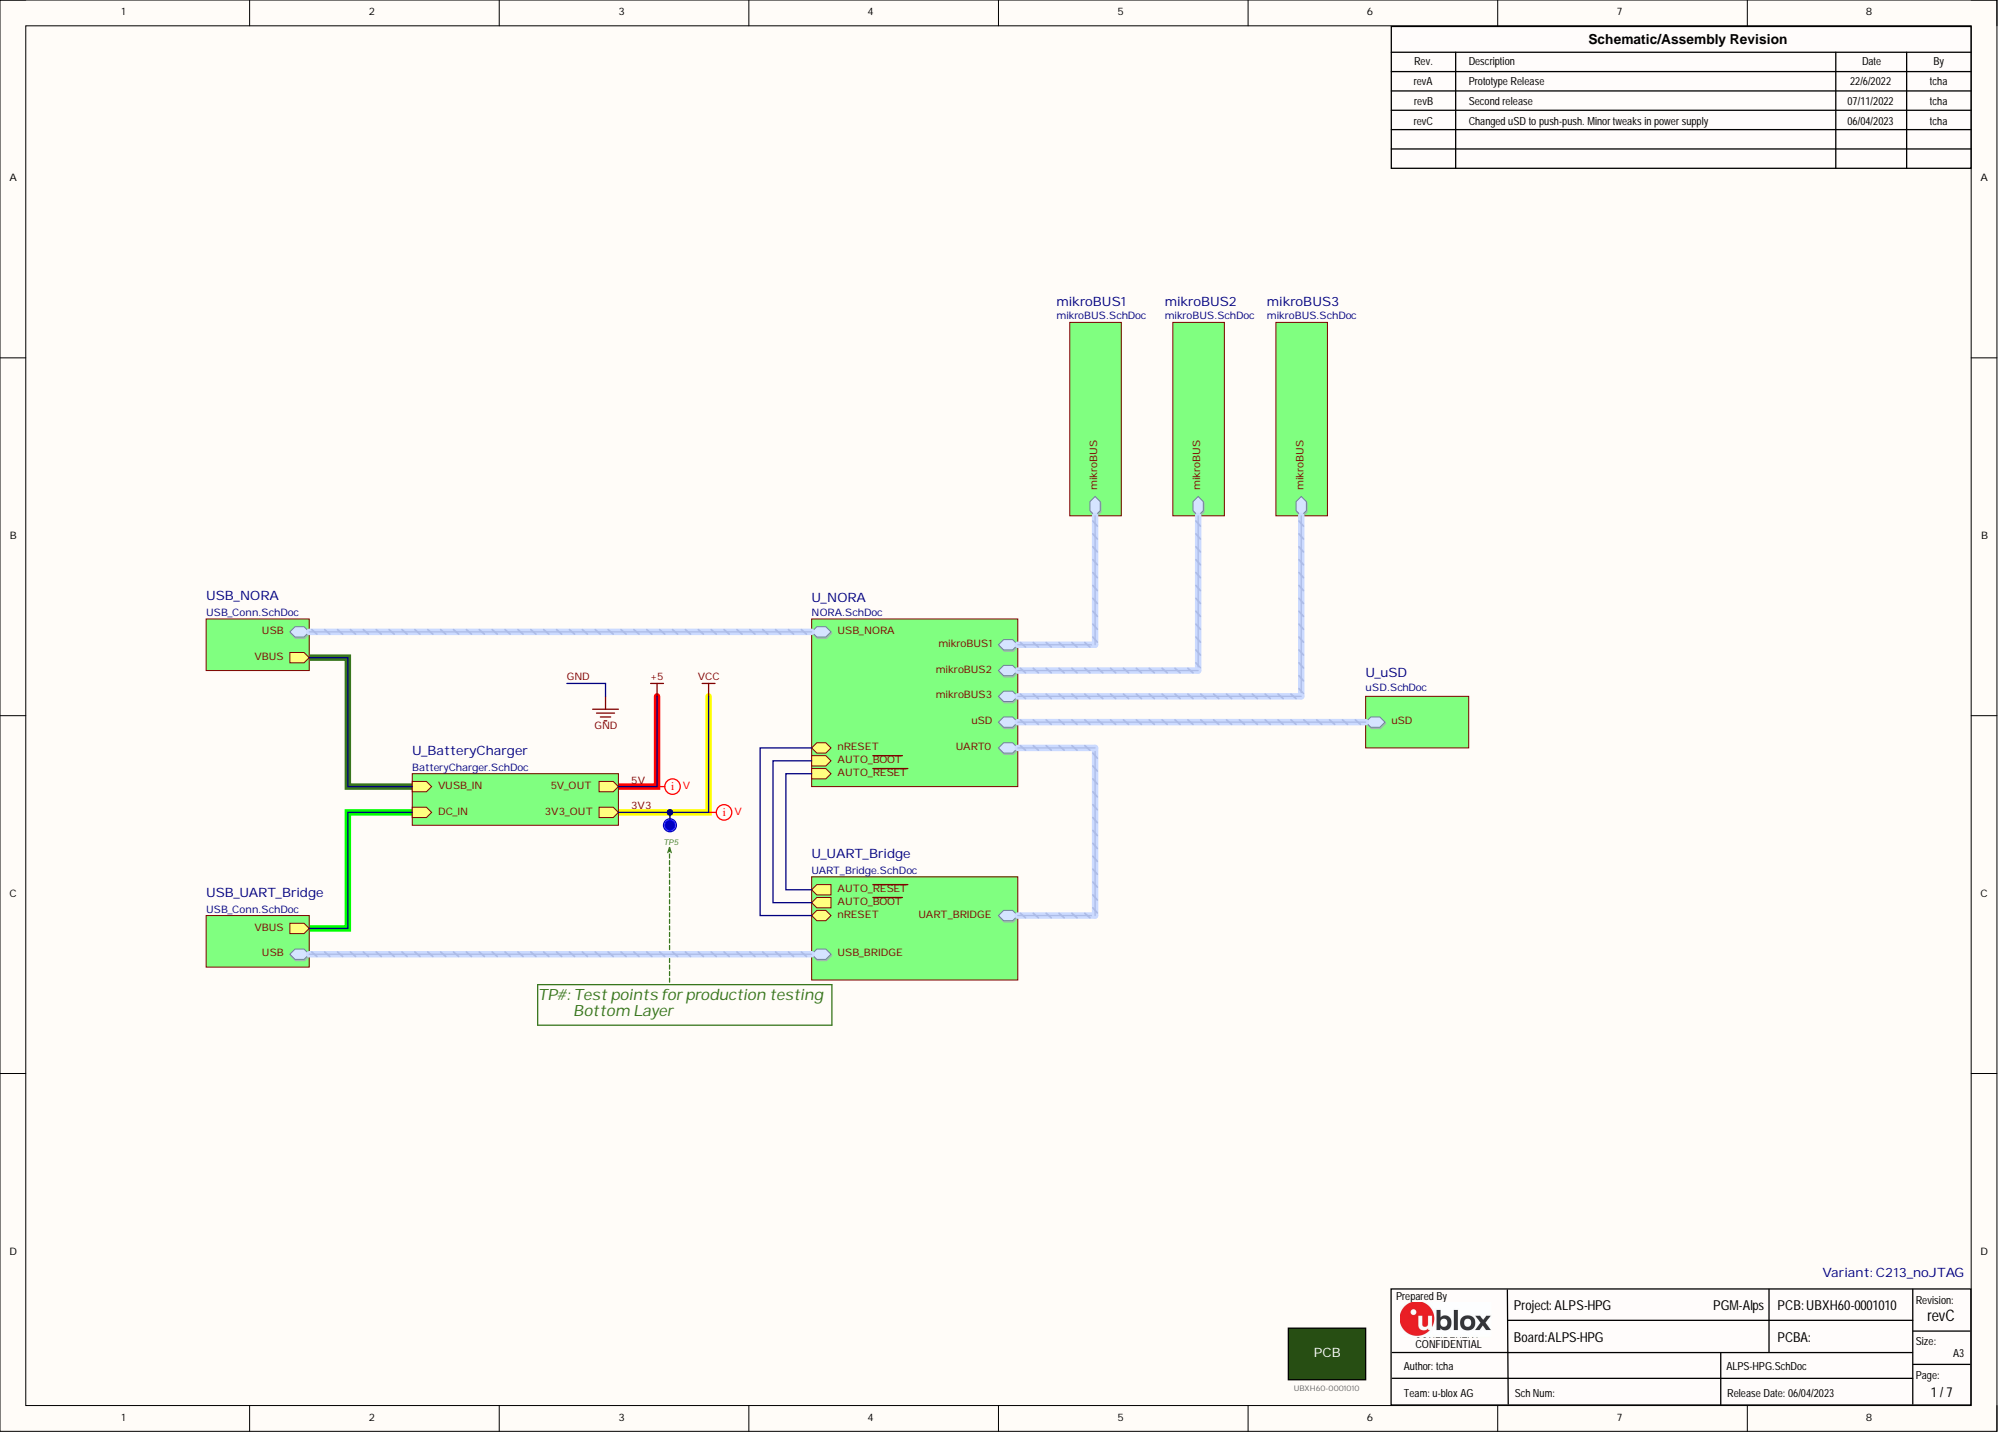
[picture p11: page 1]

Rev. | Description | Date | By
revA | Prototype Release | 22/6/2022 | tcha

revB | Second release | 07/11/2022 | tcha
revC | Changed uSD to push-push. Minor tweaks in power supply | 06/04/2023 | tcha

TP#: Test points for production testing
Bottom Layer

Prepared By CONFIDENTIAL | Project: ALPS-HPG | PCB: UBXH60-0001010 | Revision: PGM-Alps revC

Board:ALPS-HPG | PCBA:

Author: tcha | | ALPS-HPG.SchDoc

Team: u-blox AG | Sch Num: | Release Date: 06/04/2023

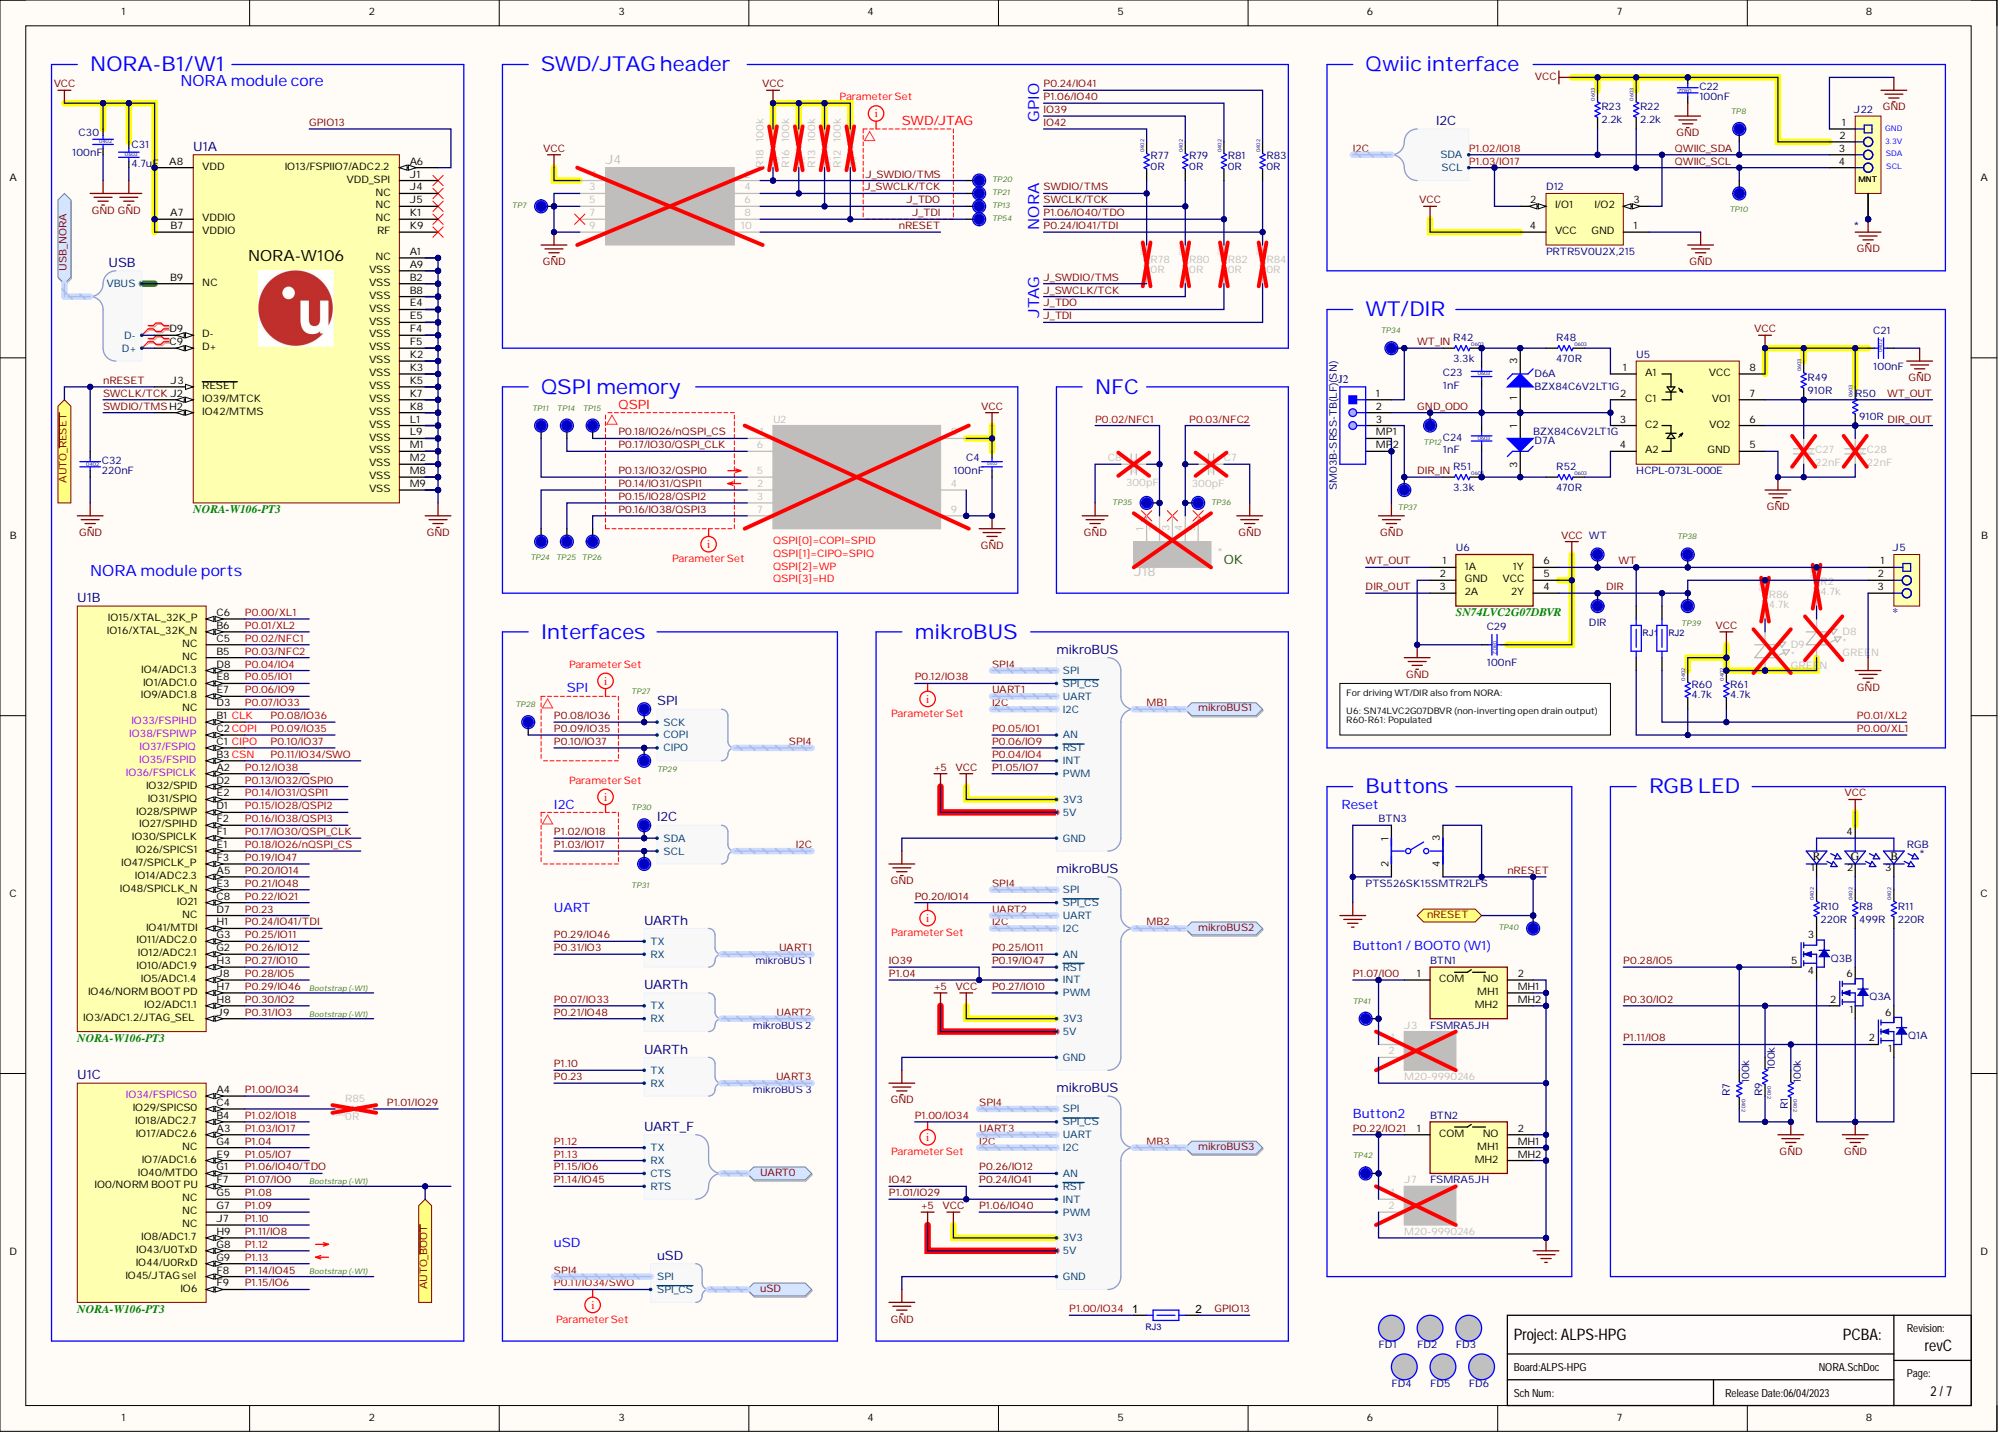
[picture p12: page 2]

A 9
B 2

SM03B-SRSS-TB(LF)(SN)

P0 .15/I O 2 8 /Q SPI 2 | 3 | 9
P0 .16/I O38 /Q SPI 3 | 7

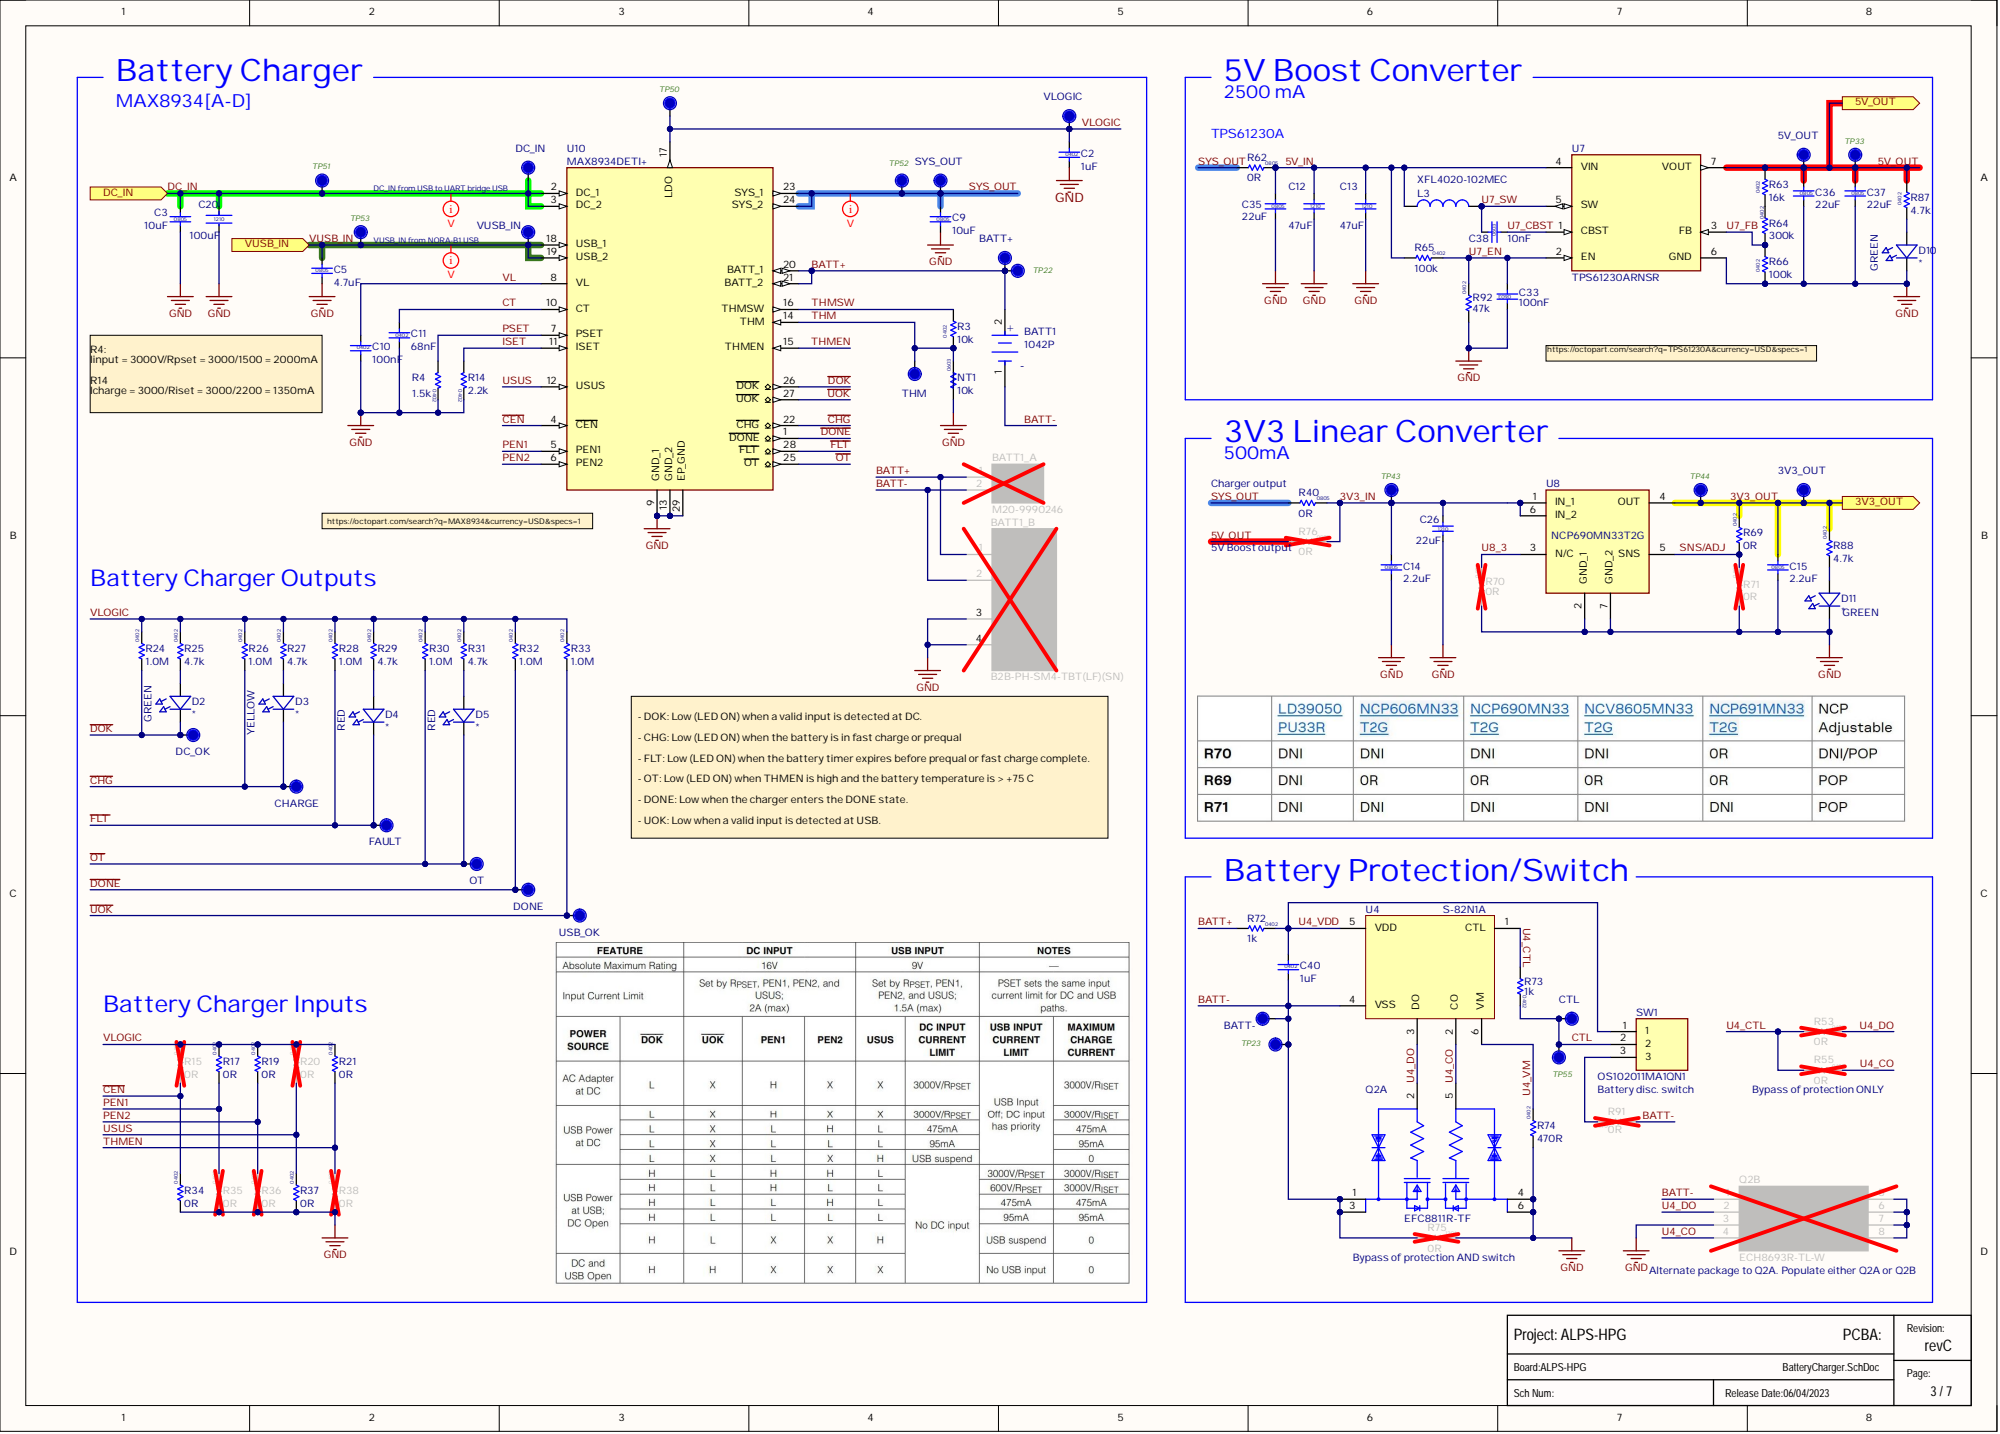
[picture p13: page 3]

DC_IN from USB to UART bridge USB

https://octopart.com/search?q=TPS61230A&currency=USD&specs=1

https://octopart.com/search?q=MAX8934&currency=USD&specs=1

B2B-PH-SM4-TBT(LF)(SN) GND

- DOK: Low (LED ON) when a valid input is detected at DC.

- CHG: Low (LED ON) when the battery is in fast charge or prequal

- FLT: Low (LED ON) when the battery timer expires before prequal or fast charge complete.

- OT: Low (LED ON) when THMEN is high and the battery temperature is > +75 C

- DONE: Low when the charger enters the DONE state.

- UOK: Low when a valid input is detected at USB.

Bypass of protection ONLY

USUS
THMEN

3 Bypass of protection AND switch | 6

GND
Alternate package to Q2A. Populate either Q2A or Q2B


Open drain NOT gate

When card is in, CD is low, uSD_CS is left floating by NOT gate
When card is out, CD is high, uSD_CS is pulled low by NOT gate


https://octopart.com/search?q=CP2102N-A02-GQFN24&currency=USD&specs=1


A 1 1 | B 2
A 1 2 | B 1


A 1 1 | B 2
A 1 2 | B 1




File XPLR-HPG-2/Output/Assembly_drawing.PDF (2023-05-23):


mamm v0.9 + Adjustable LDO, LENA-R8 pin, Mouser connectors,
Changed to u-blox standards. Changed RF paths, battery charger

View from Front side (Scale 2:1)


Assembly Notes
Orientation of components with polarity shown
with red marking or with a dot on pin 1.

No component placed on bottom side

Only testpoints for production testing

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

View from Top side (Scale 2:1)

Top View (Realistic View)

Bottom View (Realistic View)

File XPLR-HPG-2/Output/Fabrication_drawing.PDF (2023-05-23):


mamm v0.9 + Adjustable LDO, LENA-R8 pin, Mouser connectors,
Changed to u-blox standards. Changed RF paths, battery charger

Drill Drawing View (Scale 2:1)

Symbol | Count | Hole Size | Plated

10 | 0.20mm | Plated
112 | 0.30mm | Plated
1012 | 0.30mm | Plated
2 | 0.65mm | Non-Plated
2 | 0.95mm | Non-Plated
36 | 1.02mm | Plated
2 | 1.40mm | Plated
2 | 1.70mm | Plated
4 | 3.05mm | Non-Plated
1182 Total



Indicative, does not contain paste of DNI parts.


No component placed on bottom side

Only testpoints for production testing


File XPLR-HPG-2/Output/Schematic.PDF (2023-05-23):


Rev. | Description | Date | By
v1.01 | mamm v0.9 + Adjustable LD O, LENA-R8 pin, Mouser connectors, testpoints | 22/09/2022 | tcha

revA | Changed to u-blox standards. Changed RF paths, battery charger and LD O s + JTAG . | 14/10/2022 | tcha
revC | Fi xed adjustable LD O | 29/11/2022 | tcha

/8 jumpe
disconnect
ect connection between LBAND and GNSS JP7 JP8

Prepared By C O NFIDENTIAL | Project: C21 4 A L P S -H PG | PCB: UBXH60-0000969 | Revi s ion: revC

B oard:C21 revC | PCBA:

Author: tcha | High Precision GNSS Demo Board | HPG_Solution_0.SchDoc

Team: sys-sho | Sch Num: | Release Date: 29/11/2022


ZED-F9 GNSS / RTK / DR

*Battery Initial Charge: 2.3-2.8V *Intial Battery Capacity (maH): 800mAH or Greater

*Battery Charge Rate: 1mA MAX *Voff: 2.0V

*72 hours charge time from 2.0-3.1V


u-blox NINA-W106 ESP32 WiFi/BLE module

(USB-to-Serial Converter)

HIGH to LOW resets to run mode.
If RTS is HIGH, toggling DTR from
LOW to HIGH resets to bootloader.

Be careful providing
external 3.3V here as
it may compete with the 3.3V regulator.



LTE Cellular Modem
LARA-R6, LENA-R8 or SARA-R5

If U1 equals SARA-R510S then
C16, C23 : DNP

L TE_D T R 1 4 | | 3 4 5
L TE_D C D 1 3

VPP VC C C L K RS T GND

SARA-R5 VCC Design Notes:


M0=High, M1=Low -> Programmable ILIM

ILIM: Sets input current, if M0 and M1 are set to High/Low.

Different NCP69xMNyyyT2G variants:
NCP690: No enable pin
NCP691: Active Low Enable pin
NCP692: Active High Enable pin

VCC_2 (ADJ) used for :
LTE: LARA, SARA or LENA

Warning!
Adjustable and fixed have OUT and SNS/ADJ pins swapped.


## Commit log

2023-05-23 Initial release of XPLR-HPG-Hardware PCBA: C213-00C and PCBA: C214-00C
    [ALPS-HPG.GBL, ALPS-HPG.GBO, ALPS-HPG.GBP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]
2023-05-24 update XPLR-HPG-1 to revC
    [ALPS-HPG-Modular_revC_C213_noJTAG_BOM-ALPS-HPG(C213_noJTAG).xlsx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]
2024-02-20 Adding plexiglass design files for XPLR-HPG-1 kit
    [C213,C215_revC_Plexiglass_wLetters.dxf]
